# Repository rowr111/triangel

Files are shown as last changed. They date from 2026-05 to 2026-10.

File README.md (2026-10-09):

# triangel

A ceiling light fixture in the shape of a ~50cm equilateral triangle, designed to sit in the corner of a room. Built from 25 triangle PCBs (600 WS2812B LEDs total, 24 per board) and driven by custom firmware that runs ambient and sound-reactive lighting patterns.

The installation runs two pattern setlists - ambient and sound-reactive - with a d-pad, 3-position mode switch, and IR remote for control.

## System overview

Two Baochip-1x chips run under [Xous OS](https://betrusted.io/xous-book/):

- **eye** - drives the 600 WS2812 LEDs as two chains in parallel, one BIO co-processor core each, at 30 fps; manages pattern setlists and handles all user input
- **ear** - captures audio from an ICS43434 MEMS mic, measures it in 24 frequency bands, and streams the result to the eye over UART at about 28 fps. The eye uses the band levels to drive sound-reactive patterns.

## Repository structure

| Directory | Contents |
|---|---|
| [`firmware/`](firmware/README.md) | Rust firmware for both chips and the code they share |
| [`firmware/eye/`](firmware/eye/README.md) | Eye chip firmware - LED output, patterns, input handling |
| [`firmware/ear/`](firmware/ear/README.md) | Ear chip firmware - audio capture, filterbank, UART output |
| [`firmware/shared/`](firmware/shared/README.md) | Shared crate - the ear-to-eye frame format and the sound-reactive tuning |
| [`triangel previewer/`](triangel%20previewer/README.md) | Browser-based LED simulator and desktop audio tools |
| `hardware/` | KiCad PCB design files |
| [`graphics/`](graphics/README.md) | Artwork, assembly sticker sheets, and the scripts that generate them |

## Building the kernels (UART2 freed)

The ear-to-eye link uses UART2 on both chips, but a stock Xous kernel gives UART2 to its
log console. Building with the `gdb-stub` feature leaves it free. CI kernels don't have
it, so both chips use a locally built kernel in manual kernel mode.

From a xous-core checkout:

1. `cargo xtask dabao --feature gdb-stub`
2. Copy `loader.uf2` and `xous.uf2` from `target/riscv32imac-unknown-xous-elf/release/`
   into `firmware/xous_build/`. Both chips flash from that one folder.

The eye also needs a fix to the I2C driver (`libs/bao1x-hal/src/udma/i2c.rs`) that is not
in upstream xous-core, so build from a checkout that has that fix.

## Regenerating the I2S mic driver for different pins

The mic's I2S driver runs as a small precompiled BIO program
(`firmware/ear/src/i2s_bio.rs`, generated from `bio-sim/sw/i2s/main.c`). The mic
pins are compiled into it, so changing the mic wiring means regenerating it - a
firmware constant won't do it. Current pins (these match the schematic and
`firmware/ear/src/pins.rs`): BCLK=PB1, SD=PB2, WS=PB3.

To regenerate:

1. One-time: `pip install ziglang`
2. In `bio-sim/sw/i2s/main.c`, set the pin defines (the number is the PBx pin):

       #define WS_PIN  3
       #define SCK_PIN 1
       #define SD_PIN  2

3. From `bio-sim/sw`, run: `python3 -m ziglang build -Dmodule=i2s -Demit-listing=false`
   (regenerates `bio-sim/sw/i2s/i2s.rs`).
4. Copy it in: `cp bio-sim/sw/i2s/i2s.rs firmware/ear/src/i2s_bio.rs`
5. Rebuild the ear firmware.

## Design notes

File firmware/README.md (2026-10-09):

# triangel - controller firmware

The triangel fixture is driven by two Baochip-1x chips running [Xous OS](https://betrusted.io/xous-book/) (DABAO dev boards used during development):

| Chip | Role |
|---|---|
| **eye** | Drives 600 WS2812 LEDs, handles controls, renders patterns |
| **ear** | Captures audio, runs a 24-band filterbank, streams the result to eye over UART |

See [`eye/`](eye/) and [`ear/`](ear/) for crate-level documentation.

## Physical fixture

The fixture mounts in the corner of a room - an equilateral triangle cutting off the corner tip. It is made of 25 triangle PCBs (24 LEDs each) arranged in a larger triangle:

```
->  1   2   3   4   5   6   7   8   9
<- 16  15  14  13  12  11  10
->     17  18  19  20  21
<-         24  23  22
                25
```

Boards are numbered left-to-right, top-to-bottom by position. The data path snakes for shortest inter-board wire lengths (~52 mm per jump) and is split into two chains, driven in parallel:

| Chain | Eye pin | Enters at | Boards, in order | LEDs |
|---|---|---|---|---|
| 1 | PB4 | board 1 | 1-9, 16, 15, 14 | 288 |
| 2 | PB5 | board 13 | 13, 12, 11, 10, 17-21, 24, 23, 22, 25 | 312 |

## Eye <-> ear communication

The ear sends one frame for each 32 ms of audio it captures, about 28 per second, to the eye over a single UART wire. The frame carries 24 band levels, the overall loudness (absolute and relative to recent music), how sharply the spectrum just rose, and the bass level. The eye turns those into beats, drops, per-band onsets and the Auto sound-mode decision.

The baud rate and frame layout are defined once, in the [`shared/`](shared/) crate that both chips build against; see its README for the byte layout.

## Building

Rust stays at 1.90.0: the Xous library that `install-toolkit` downloads only works with the version it was built for. One-time setup:

```powershell
rustup toolchain install 1.90.0
rustup override set 1.90.0   # in the xous-core checkout and in this repo's root
cargo xtask install-toolkit  # in the xous-core checkout
```

Install the pre-commit hook, which runs the checks in `.pre-commit-config.yaml` before each commit (needs Python):

```powershell
pip install pre-commit
pre-commit install   # in this repo's root
```

Build and flash with the Baochip VS Code extension: out-of-tree, kernel mode manual, kernel files from `firmware/xous_build`. Never use ci-sync; it replaces the kernels built in the root README's "Building the kernels".

## Regenerating the LED map

If the PCB geometry or board gap changes:

```powershell
# 1. In "triangel previewer/": regenerate led_map.js
node generate_map.js

# 2. Copy the output into firmware/eye/src/led/map.rs

# 3. In firmware/eye/: regenerate src/led/geom.rs from map.rs
python tools/gen_geom.py
```

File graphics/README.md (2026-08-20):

# graphics

Artwork and the assembly sticker sheets. Every sheet is 89 x 127 mm - Japanese L size - at
600 dpi.

| File | What |
|---|---|
| `triangel graphic.*` | artwork for triangle shapes |
| `triangel_stickers_L.*` | Tile orientation stickers, 12 mm, 25 numbered + 5 blanks |
| `triangel_input_overlay_L.*` | Input plate overlay, 81 x 61 mm, 1 per sheet |
| `triangel_remote_overlay_L.*` | IR remote overlay, 31 x 51 mm, 4 per sheet |

## Printing

Convenience store photo print on L sticker paper, not document print. PNG and JPG are the
same image - use the JPG if the machine will not take PNG.

## Regenerating

    pwsh graphics\make_input_overlay.ps1
    pwsh graphics\make_remote_overlay.ps1

Windows PowerShell only - they draw with `System.Drawing` - and they write the PNG and JPG
next to themselves. `make_input_overlay.ps1` parses
`../hardware/input-enclosure/InputEnclosure.py`, so the overlay tracks the enclosure.

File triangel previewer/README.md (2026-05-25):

# Triangel Previewer

Browser-based simulator for the Triangel LED installation - 600 LEDs across 25 triangle PCBs. Open `index.html` directly in a browser, no server needed.

## Requirements

- **Node.js** - required only for `bridge.js` (live Baochip data) and `generate_map.js` (regenerating the LED map).
- **npm packages** - install once before using the bridge: `npm install`

## Files

| File | Purpose |
|---|---|
| `index.html` | Renderer - open this in a browser |
| `led_map.js` | Pre-generated LED positions - do not edit by hand |
| `generate_map.js` | Regenerates `led_map.js` - run if geometry changes |
| `bridge.js` | Serial-to-WebSocket bridge for live Baochip data |
| `bridge.config.json` | Bridge configuration |
| `ear_sim.py` | Desktop audio simulator - streams mic or system audio to the ear board over USB serial |

## Live data from the Baochip

When the Baochip is connected, `bridge.js` reads its serial output and streams frames to the browser over a local WebSocket. The browser automatically switches from `animation.js` to live data when the bridge connects, and falls back when it disconnects. A **"bridge live"** indicator appears in the top-right corner.

### Setup

Install dependencies (one time):

```powershell
npm install
```

Edit `bridge.config.json` to set your serial port:

```json
{
  "serial": "COM3",
  "baud": 921600,
  "wsPort": 8080
}
```

Then run the bridge:

```powershell
node bridge.js
```

All config values can be overridden on the command line:

```powershell
node bridge.js --serial COM5 --baud 460800 --ws-port 9000
```

### Frame format

The Baochip sends **1800 bytes per frame** - one RGB triplet per LED, in chain order. Byte offset for a given LED is `chainIdx * 3`. The bridge forwards each complete frame as a binary WebSocket message.

## Chain wiring

Single daisy chain, 600 LEDs in series. Traversal order:

- **Row by row, top to bottom**
- **Right to left within each row**
- **D1->D24 within each board**

Board order in chain (chain positions 0-599):

| Chain pos | Board IDs (right -> left) |
|---|---|
| 0-215 | Row 1: boards 9, 8, 7, 6, 5, 4, 3, 2, 1 |
| 216-383 | Row 2: boards 16, 15, 14, 13, 12, 11, 10 |
| 384-503 | Row 3: boards 21, 20, 19, 18, 17 |
| 504-575 | Row 4: boards 24, 23, 22 |
| 576-599 | Row 5: board 25 |

`chainIdx` in `led_map.js` encodes this for every LED. When the Baochip streams a frame over USB, byte triplet `chainIdx * 3` is the RGB for that LED.

## Desktop audio simulator (ear_sim.py)

`ear_sim.py` streams desktop audio or microphone input to the ear board over USB serial, using the same 1025-byte frame format the real ICS43434 mic produces. This lets the full mel filterbank and UART output path run on real music without the mic circuit being assembled. Build the ear firmware with the `uart-audio` feature to use it.

### Dependencies

```powershell
pip install pyaudiowpatch numpy pyserial
```

### Usage

```powershell
# Stream system speakers (default) to the ear board on COM6
python ear_sim.py

# Use microphone instead
python ear_sim.py --mic

# List available audio devices to find the right index
python ear_sim.py --list-devices

# Specific device index (--mic mode only)
python ear_sim.py --mic --device 2

# Different serial port
python ear_sim.py --port COM4
```

The script auto-detects the WASAPI loopback device for the default speakers. A live bar display shows RMS level and frame rate while running. Press Ctrl+C to stop.

## Regenerating the LED map

Only needed if board geometry or gap size changes:

```powershell
node generate_map.js
```

Tweak `BOARD_GAP` in `generate_map.js` (currently 2mm) to adjust spacing between boards.

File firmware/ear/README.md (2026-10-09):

# triangel - ear firmware

Audio processor firmware for the triangel fixture. Runs on a Baochip-1x under [Xous OS](https://betrusted.io/xous-book/) (DABAO dev board used during development). See [`../README.md`](../README.md) for the overall system and physical fixture description.

## What this is

The **ear** chip captures audio, measures it in 24 frequency bands, and streams the result to the **eye** chip over UART at about 28 fps.

Pipeline per frame (32 ms):

```
mic (I2S, 48 kHz)  ->  2:1 decimate  ->  768-sample frame  ->  24 bandpass filters  ->  normalize  ->  UART TX  ->  eye
```

The 24 bands span 40 Hz to 12 kHz, each a constant ratio above the last (about a third of an octave), so every band covers the same musical interval. It is built like a hardware spectrum analyzer: one bandpass filter per band, squaring and averaging each filter's output over the frame. No FFT is involved, so there is no windowing and the filters run continuously across frame boundaries.

Each frame carries two kinds of value, on purpose:

- **Bands** are normalized against recent music, so they give spectral shape but never go dark in a quiet room.
- **Level** and **bass** are absolute dBFS, so they do. dB SPL is roughly dBFS + 120.

It also carries the level normalized against recent loudness, and the spectral flux the eye uses for beat detection. The frame layout is in [`../shared/README.md`](../shared/README.md).

## Hardware

| Thing | Detail |
|---|---|
| Chip | Baochip-1x - 350 MHz VexRiscv RV32-IMAC, 2 MB SRAM, 4 MB ReRAM, no FPU |
| Microphone | ICS43434 MEMS mic (JLCPCB C5656610), I2S slave, clocked by a BIO core: PB1 = BCLK, PB2 = SD, PB3 = WS |
| Eye link | PB14 (UART2 TX, pin 15) -> eye PB13 (UART2 RX, pin 16), single wire + GND |

## Audio configuration

| Setting | Value | Notes |
|---|---|---|
| Mic sample rate | 48 kHz | Inside the ICS43434's high-performance range |
| Pipeline sample rate | 24 kHz | 2:1 box-average decimation; 12 kHz Nyquist |
| Bit depth | 24-bit | Top 16 bits used |
| Channels | Mono | Select pin tied low on PCB = left channel |
| Frame size | 768 samples | 32 ms of audio per frame. About 28 fps, because audio that arrives while a frame is being processed is skipped |

All of these derive from three constants at the top of [`src/audio.rs`](src/audio.rs).

## Project structure

```
src/
+-- main.rs       - entry point; capture -> filterbank -> UART loop
+-- audio.rs      - I2sAudio: ICS43434 mic through a BIO core
+-- i2s_bio.rs    - the BIO program that clocks the mic (generated)
+-- bands.rs      - BandProcessor: the 24-band filterbank and normalization
+-- uart_out.rs   - UartOut: sends each frame to the eye
+-- pins.rs       - pin assignments
+-- diag.rs       - USB-serial output: boot stages, heartbeat, command input
+-- console.rs    - mic diagnostic commands
```

Code shared with the eye (frame format, tuning) lives in [`../shared/`](../shared/).

## Building

Build via the Baochip VSCode extension (`buildMode: out-of-tree`).

## Mic diagnostic console

The ear has no log console - UART2 carries the audio link to the eye, so the board runs the `gdb-stub` kernel and the log server has no UART left to print on. Everything the firmware reports goes over **USB CDC serial** instead.

The board presents two serial ports: the bootloader's and the running application's. The console is on the application's.

Until the first keystroke the board prints a liveness line every 2 s naming the startup stage it reached and how many bytes it has received, so a stalled boot says where it stopped. Commands are a single character and act on the keystroke - no Enter, because terminals disagree on whether that sends CR, LF, or both.

| Key | What it does |
|---|---|
| `c` | Record 3 s silently, then print the level per 100 ms. The test that answers whether the mic hears you |
| `f` | Measure a quiet second against a noisy one, per octave band. About 30 dB more sensitive than `c`, and works with any sound |
| `r` | Hex-dump the raw 24-bit words after settling |
| `s` | Count samples for 1 s and compare against the expected 48000 Hz |
| `t` | 1 s of statistics: min, max, DC offset, RMS |
| `m` | Live level meter for 15 s |
| `p` | Filterbank time per frame |
| `n` | Live normalization references and the level they scale |
| `?` | Help |

`p`, `n` and `?` are answered without interrupting audio. The rest run on the audio thread between frames, so the eye stops receiving frames while one is in progress - up to 15 s for `m`, 3 s or less for the others. The eye decays to silence after 200 ms without a frame and recovers on its own; because its Auto-mode arm and release times are both 30 s, even the longest command will not flip it out of sound-reactive mode.

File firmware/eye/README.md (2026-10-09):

# triangel - eye firmware

LED controller firmware for the triangel fixture. Runs on a Baochip-1x under [Xous OS](https://betrusted.io/xous-book/) (DABAO dev board used during development). See [`../README.md`](../README.md) for the overall system and physical fixture description.

## What this is

The **eye** chip drives 600 WS2812 LEDs across 25 triangle PCBs. It manages:

- A 30 fps render loop driving two LED chains in parallel, one BIO co-processor core each
- Two pattern setlists (ambient and sound-reactive), stepping every 3 minutes with a transition between patterns
- D-pad + 3-position switch for brightness, pattern stepping, hold, and sound mode
- IR remote (same functions as the physical controls)
- Audio frames from the **ear** chip over UART, from which it detects beats, drops and per-band onsets

## Hardware

| Thing | Detail |
|---|---|
| Chip | Baochip-1x - 350 MHz VexRiscv RV32-IMAC, 2 MB SRAM, 4 MB ReRAM, no FPU |
| BIO cores | 4x PicoRV - two for WS2812 bit-timing, one for IR capture |
| LED output | Two WS2812B chains: PB4 (288 LEDs) and PB5 (312 LEDs) |
| Ear link | PB13 (UART2 RX) |
| Controls | D-pad (5 buttons) + 3-position switch + IR receiver (PC8) |

All pin assignments are in [`src/pins.rs`](src/pins.rs).

## Project structure

```
src/
+-- main.rs      - entry point; 30 fps render loop
+-- setlist.rs   - the two setlists, cycling, transitions, brightness, sound mode
+-- audio.rs     - receives ear frames; beat, drop and activity detection
+-- pins.rs      - pin assignments
+-- diag.rs      - boot stages and heartbeat over USB serial
+-- led/
|   +-- mod.rs          - LedOutput: the WS2812 chains, or the USB previewer
|   +-- ws2812_pair.rs  - two-chain WS2812 driver
|   +-- map.rs          - LED_MAP: world position of every LED (generated)
|   +-- geom.rs         - per-LED distances, angles and grid buckets (generated)
|   +-- grid.rs         - spatial lookup: the LEDs near a point or segment
+-- patterns/
|   +-- mod.rs          - Pattern trait and shared helpers
|   +-- transition.rs   - blends from one pattern to the next
|   +-- glints.rs       - brief white flashes on single LEDs, shared by Shimmer and Rainbow
|   +-- ripples.rs      - raindrop ring trains on black, shared by Raindrop and Drizzle
|   +-- ambient/        - patterns that ignore sound
|   +-- reactive/       - patterns driven by sound
+-- input/
    +-- mod.rs          - InputEvent queue
    +-- buttons.rs      - d-pad and switch polling, debounce
    +-- buttons/        - gpio.rs (wired direct) or expander.rs (input board over I2C)
    +-- ir.rs, nec_capture.rs, nec_rx.rs - IR remote, NEC decoded on a BIO core
    +-- previewer.rs    - on-screen controls from the previewer
```

Code shared with the ear (frame format, sound tuning) lives in [`../shared/`](../shared/).

## Building

Build via the Baochip VSCode extension (`buildMode: out-of-tree`). Optional features can be added under **Extra Features** in the extension settings:

| Feature | Purpose |
|---|---|
| `previewer` | Send LED frames over USB serial to the browser simulator instead of driving WS2812, and take on-screen control input |
| `bringup` | Stream boot stages, a heartbeat, audio link stats and IR activity over USB serial. Silent when combined with `previewer`, whose serial stream is binary |
| `input-board` | Read the d-pad and switch from the separate input board (MCP23008 over I2C) instead of eye GPIOs |

## Using the previewer

The previewer is a browser-based LED simulator at `../../triangel previewer/`. It can receive live frames from this firmware over USB serial.

1. Enable the `previewer` feature in the Baochip extension settings and build
2. Flash and boot the DABAO
3. In the previewer directory: `npm install` (first time), then `node bridge.js`
4. Open `index.html` in a browser - it will show the live pattern output

Bridge defaults: COM3, 921600 baud, WebSocket port 8080. Override via `bridge.config.json` or CLI flags.

## Adding a pattern

See [PATTERNS.md](PATTERNS.md).

## Sound reactivity

Each render frame, reactive patterns get an `Audio` snapshot built from the ear's frames: 24 band levels, a per-band onset (`rise`), overall loudness relative to recent music, and one-frame `beat` and `drop` flags. Detection thresholds and every pattern's sound tuning are in [`../shared/src/tuning.rs`](../shared/src/tuning.rs).

Sound mode is set by the 3-position switch, or cycled by the remote's gear button:

| Position | Behaviour |
|---|---|
| Off | Always the ambient setlist |
| Auto | The reactive setlist once the room has been loud for a sustained stretch, back to ambient once it has been quiet for one |
| On | Always the reactive setlist |

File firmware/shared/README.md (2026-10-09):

# triangel-shared

Code both chips build against, so the **ear** (audio) and the **eye** (LEDs) cannot disagree. No dependencies and no OS requirements.

## `frame` - the ear -> eye frame

The ear sends one `BandFrame` for each 32 ms of audio it captures, about 28 per second, over UART. Baud rate, band count and frame length are constants in [`src/frame.rs`](src/frame.rs) (`EAR_UART_BAUD`, `BAND_COUNT`, `FRAME_LEN`).

### Wire format (58 bytes, little-endian)

| Offset | Size | Content |
|---|---|---|
| 0x00 | 1 | Sync byte `0xAA` |
| 0x01-0x30 | 48 | `bands`: 24 x u16, band 0 (lowest) first |
| 0x31-0x32 | 2 | `level`: overall loudness, absolute dBFS |
| 0x33-0x34 | 2 | `level_norm`: loudness relative to the recent loudest and quietest |
| 0x35-0x36 | 2 | `flux`: how much the whole spectrum rose this frame |
| 0x37-0x38 | 2 | `bass`: level of the lowest bands, absolute dBFS |
| 0x39 | 1 | XOR checksum of bytes 0x01-0x38 |

`bands` are normalized against recent music, so they show spectral shape but never go dark in a quiet room. `level` and `bass` are absolute, so they do. dB SPL is roughly dBFS + 120 with this microphone.

Values go on and off the wire through `level_to_wire` / `level_from_wire` (dBFS) and `norm_to_wire` / `norm_from_wire` (0.0-1.0).

### Usage

```rust
use triangel_shared::frame::{BandFrame, FRAME_LEN};

// ear
let mut buf = [0u8; FRAME_LEN];
frame.encode(&mut buf);

// eye - None on a bad sync byte or checksum
if let Some(frame) = BandFrame::decode(&buf) { /* ... */ }
```

The eye receives a byte stream, not whole frames. `FrameAssembler::feed` takes one byte at a time, finds the sync byte, and returns a `BandFrame` each time one completes.

## `tuning` - sound-reactive tuning

Every knob for beat, onset and drop detection, the Auto sound-mode switch, each reactive pattern, and the ear's normalization, in one file: [`src/tuning.rs`](src/tuning.rs). The `ear` section needs the ear reflashed and `BASS_BANDS` needs both chips; everything else only the eye.

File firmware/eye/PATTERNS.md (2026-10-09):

# Writing patterns

A pattern implements the `Pattern` trait in `src/patterns/mod.rs`: called once per frame with the current time and this frame's `Audio`, it fills in a color per LED. Ambient patterns live in `src/patterns/ambient/` and ignore `audio`; sound-reactive ones live in `src/patterns/reactive/`.

## Minimal example

```rust
// src/patterns/ambient/your_pattern.rs
use crate::audio::Audio;
use crate::led::map::LED_MAP;
use crate::patterns::{Frame, Pattern};

pub struct YourPattern;

impl Pattern for YourPattern {
    fn render(&mut self, t_ms: u32, _audio: &Audio, out: &mut Frame) {
        for (i, led) in LED_MAP.iter().enumerate() {
            // led.wx, led.wy - position in mm
            out[i] = [r, g, b];
        }
    }
}
```

Then:

1. Add `pub mod your_pattern;` to `src/patterns/ambient/mod.rs` (or `reactive/mod.rs`).
2. Add `Box::new(YourPattern)` to `ambient_patterns()` (or `reactive_patterns()`) in `src/setlist.rs`.

`out[i]` belongs to `LED_MAP[i]`. `t_ms` is a `u32` and wraps after 49.7 days, so compare times with `wrapping_sub`, never `<` or `>=`.

A pattern is only rendered while it is on screen or fading out, so time jumps when it comes back. Override `on_enter(&mut self, t_ms)` to reset whatever should start fresh each time it comes on screen; it runs before the first frame after the pattern has been off screen for more than half a second.

## World coordinates

```
origin: top-left of fixture
x: increases rightward, 0-517 mm
y: increases downward,  0-436 mm

WORLD_CX  = 258 mm  - horizontal centre
WORLD_TOP =   6 mm  - topmost LED
WORLD_BOT = 436 mm  - apex (board 25, room corner)
WORLD_H   = 430 mm  - total height
```

These constants, plus `WORLD_CENTROID_X` / `WORLD_CENTROID_Y`, are in `crate::led::map`.

## Utilities

```rust
// src/patterns/mod.rs
hsv(h, s, v) -> [u8; 3]     // h: 0-360, s/v: 0-1
lerp(a, b, t) -> f32
sin_sum(a_sin, a_cos, b_sin, b_cos)  // sin(a + b); see Performance
mix_rgb(a, b, t)            // lerp per channel, f32 RGB
ramp(&stops, t)             // color along (position, color) stops
smoothstep(t) -> f32        // clamped to 0-1
wrap360(h) -> f32           // hue into 0-360, for inputs within one turn of range
cycle(t_ms, period_ms)      // 0-1 position in a repeating period
fold_ms(t_ms, rate)         // t_ms folded to one period of a rad/ms rate
hash2(a, b), knuth_hash(x), tile_hash(led)
Rng::new(seed)              // .f32(), .next_u32(), .range_u32(min, max), .below(n), .pick(&items)
free_or_oldest(slots, now_ms, is_free, start_ms)  // a free slot in a pool, else the oldest
Shot                        // a flash held then faded; .level(t_ms), .end_ms()
phase_phasors()             // see Performance
```

Shared building blocks:

- `glints::Glints` / `GlintStyle` - brief white flashes on single LEDs, landing mostly on the bright ones. Draw the frame, then call `update` over it.
- `ripples::Ripples` / `RippleStyle` - raindrop ring trains on black. The pattern picks where and when a drop lands (`spot`, `land`); `draw` renders.

Fixed geometry in `crate::led::geom` (generated by `tools/gen_geom.py`): per LED, `DIST_C[i]` and `THETA_C[i]` (distance and angle from the centroid) and `DIST_APEX[i]`; per board, by board id, `BOARD_CENTER` and `BOARD_Y_RANGE`; and `BOARD_COUNT`, `LEDS_PER_BOARD`, `DIST_C_MAX`. The triangle's left and right edges are `WORLD_LEFT` / `WORLD_RIGHT` in `crate::led::world`.

`crate::led::grid` buckets LEDs by position: `for_each_near(x, y, reach, f)` and `for_each_near_seg(a, b, reach, f)` call `f` with the index of each LED near a point or a segment.

## Performance

The chip has no floating-point hardware, so every `f32` operation is a library call and `sin`/`atan2`/`sqrt`/`powf` cost hundreds of cycles. A frame is 33 ms, of which about 9.4 ms goes to clocking out the strips - one `sin` per LED is affordable, six is not. Keep work out of the per-LED loop:

- Values fixed by LED position belong in `led::geom` or a table built in `new()`, not recomputed each frame.
- Localized shapes scatter over `led::grid` rather than every LED testing every source.
- `sin(per_led + per_frame)` needs no `sin` per LED: store `sin`/`cos` of the per-LED part, take `sin`/`cos` of the frame's angle once, and combine them with `sin_sum`. `phase_phasors()` covers hash-quantized offsets.
- Integer math per LED where possible, as Shimmer and Flame do: values in Q12 (x4096 = 1.0), lookup tables for curves and colors. A few float calls per frame are fine.
- Wrap time to the term's period before converting to `f32` (`(t_ms % PERIOD_MS) as f32`): raw `t_ms` loses sub-frame precision after hours of uptime.

The previewer caps at 30 fps and runs a few ms faster than the fixture, so it can show a pattern is too slow but can't confirm one is fast enough.

## Sound-reactive patterns

`Audio` (`src/audio.rs`) is this frame's view of the sound:

| Field | Meaning |
|---|---|
| `bands: [f32; 24]` | Band levels 0-1, lowest frequency first. Normalized, so they keep their shape when quiet |
| `rise: [f32; 24]` | How far each band just jumped above its own recent average, 0-1 |
| `level_norm` | Loudness relative to recent music, 0-1 |
| `beat`, `beat_strength` | `beat` is true for the one frame a beat lands; strength is 0-1 |
| `drop` | True for the one frame the bass returns after a breakdown |

A reactive pattern has to look good at every level, silence included.

Put a reactive pattern's tuning constants in their own module in `../shared/src/tuning.rs`, alongside the detection thresholds they interact with.

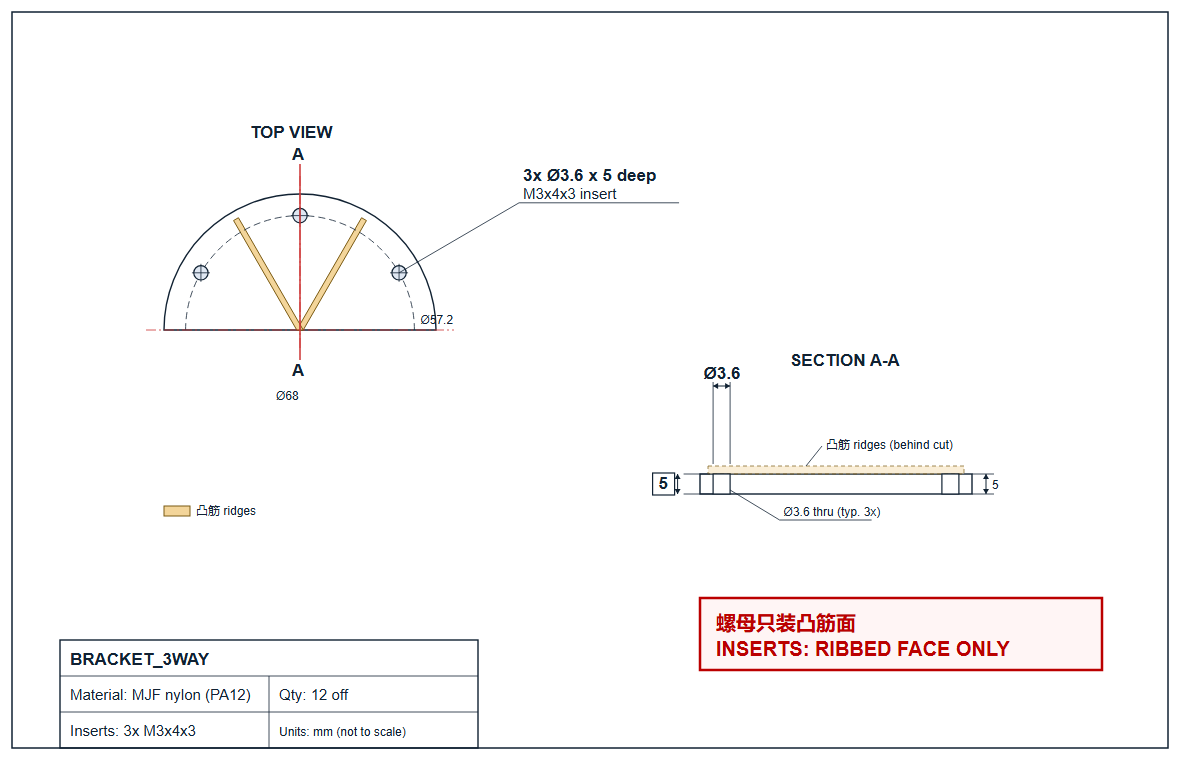
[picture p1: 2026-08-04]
hardware/brackets/triangel brackets/BRACKET_3WAY_insert_drawing.png

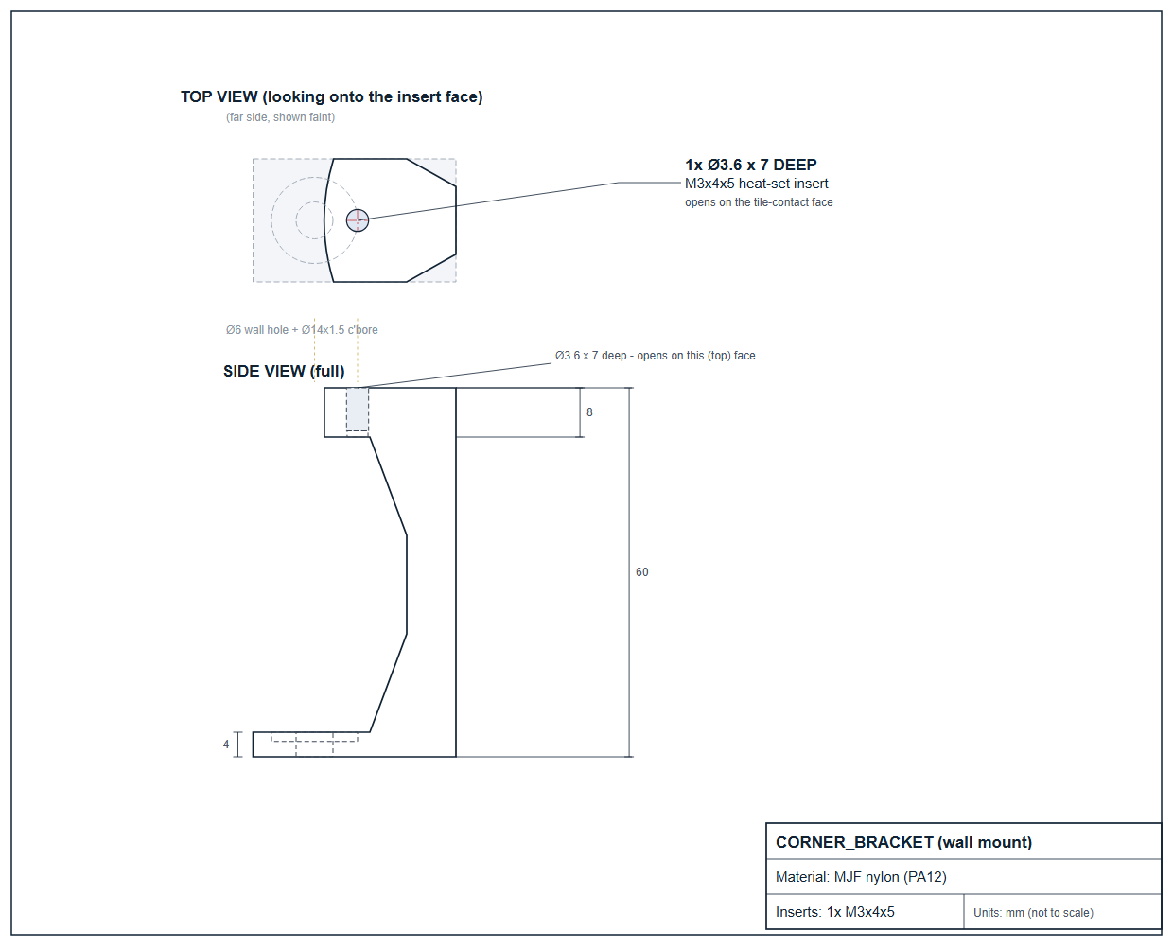
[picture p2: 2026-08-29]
hardware/brackets/CornerBrackets/CORNER_BRACKET_insert_drawing.png

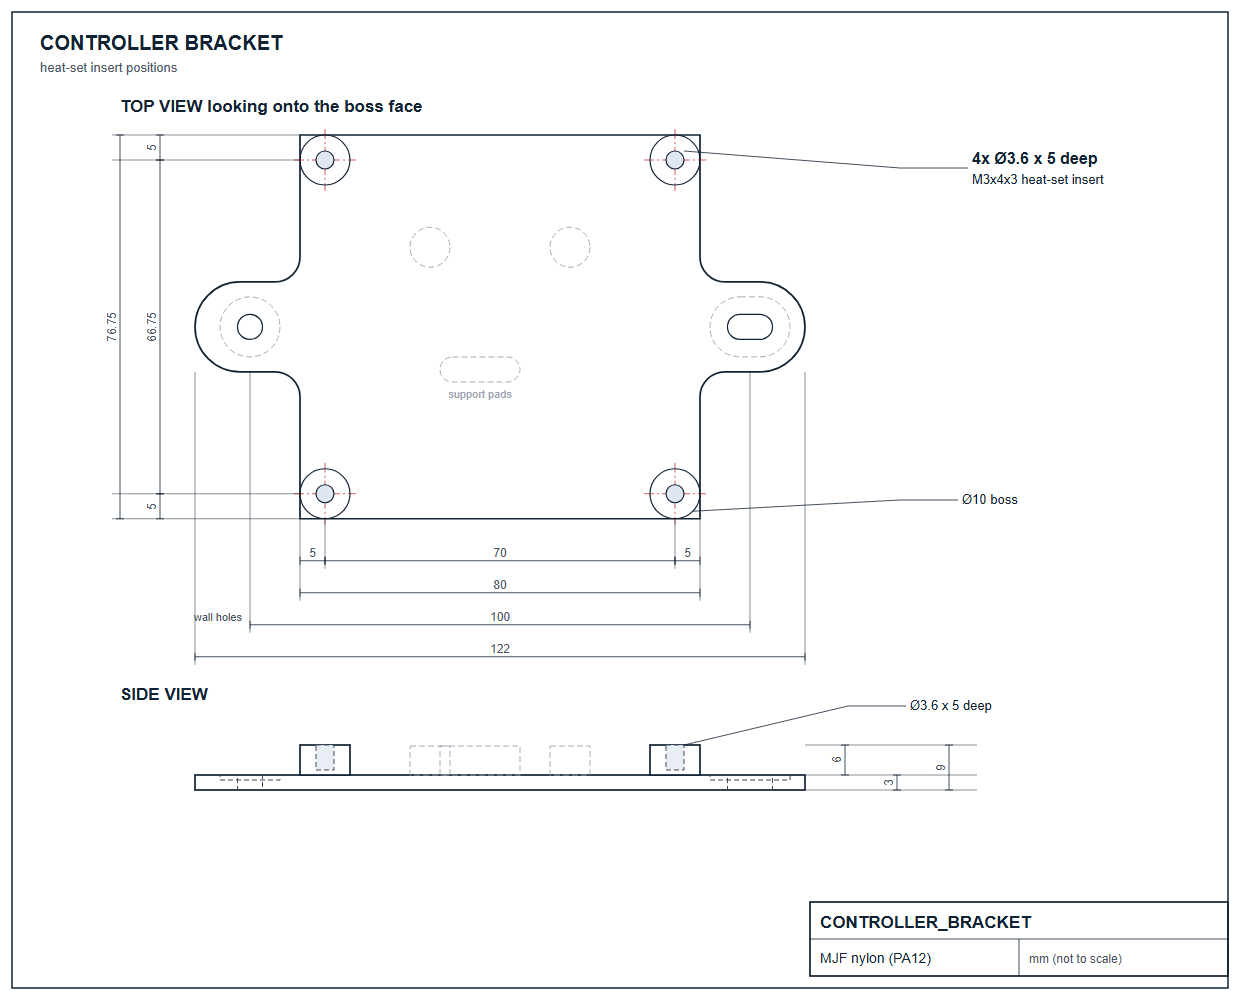
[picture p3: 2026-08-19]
hardware/brackets/controller bracket/CONTROLLER_BRACKET_insert_drawing.png

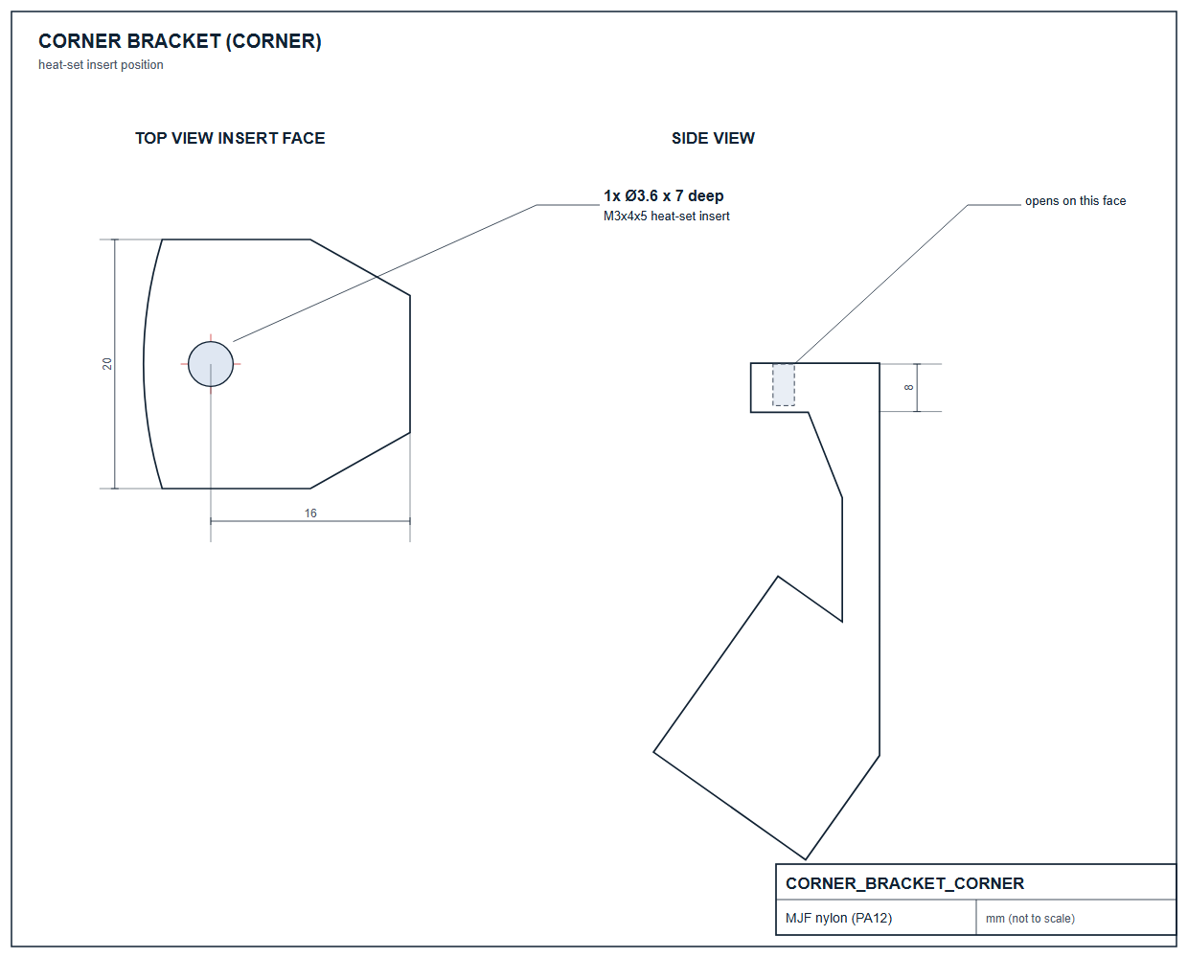
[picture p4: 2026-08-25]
hardware/brackets/CornerBracketsCorner/CORNER_BRACKET_CORNER_insert_drawing.png

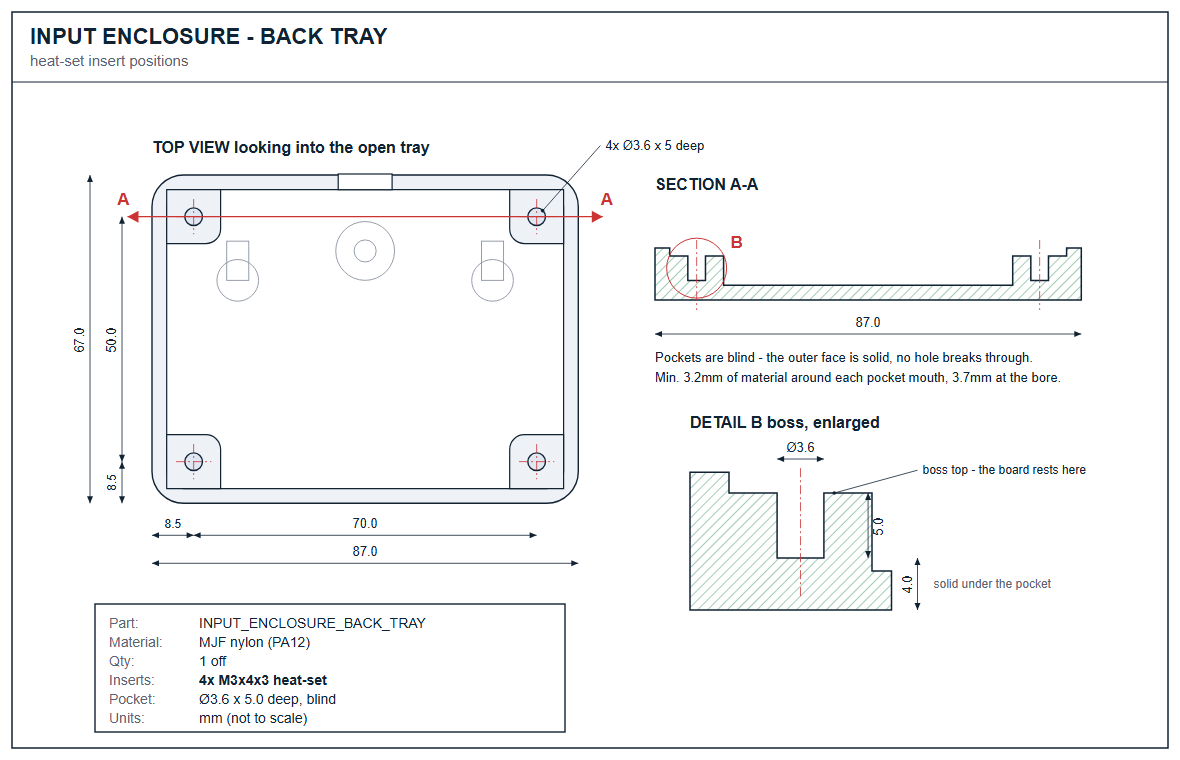
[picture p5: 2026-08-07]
hardware/input-enclosure/BACKTRAY_insert_drawing.png

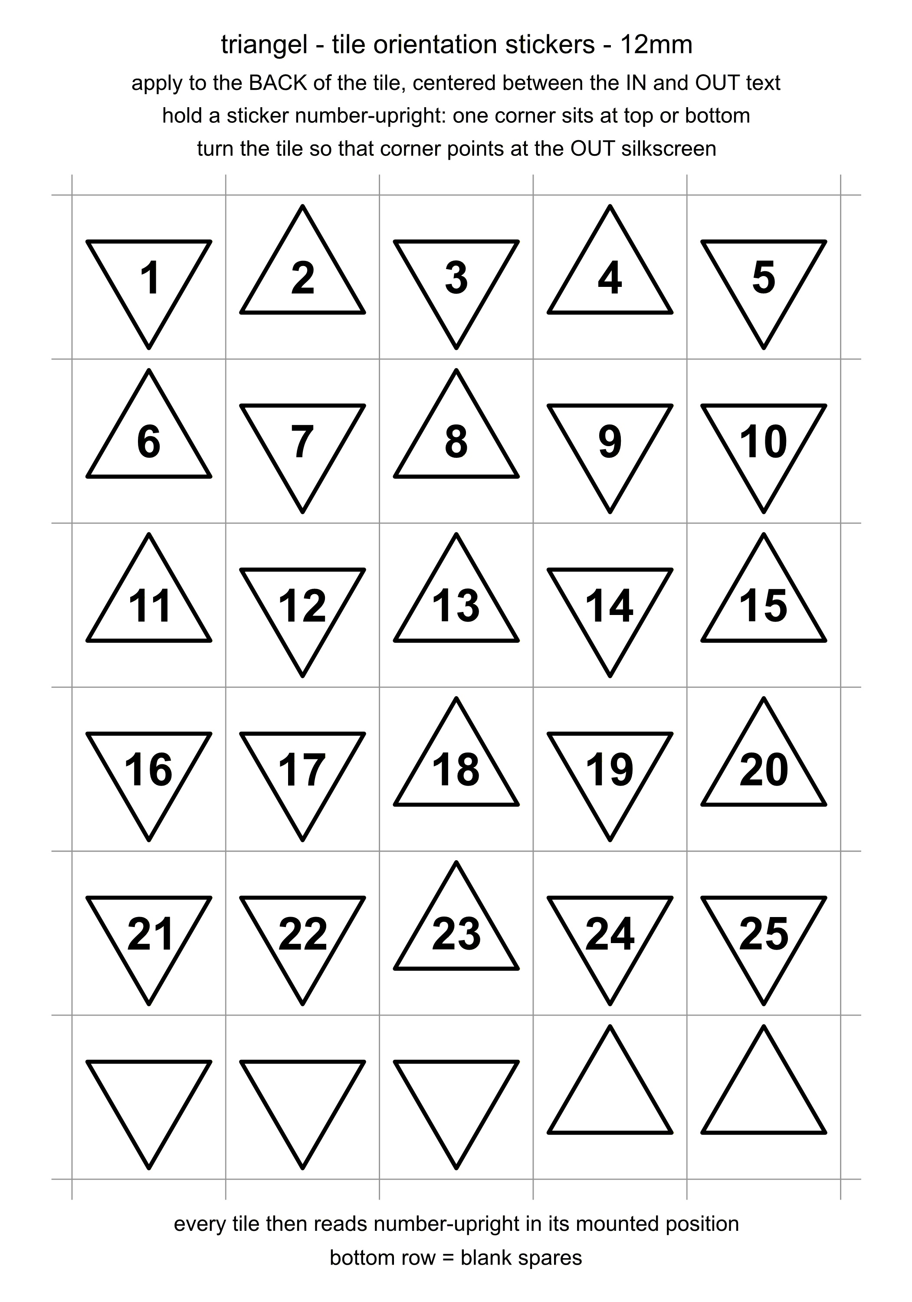
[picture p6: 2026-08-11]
graphics/triangel_stickers_L.jpg

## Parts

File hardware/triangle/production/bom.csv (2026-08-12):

Designator | Footprint | Quantity | Value | LCSC Part #
C1, C10, C11, C12, C13, C14, C15, C16, C17, C18, C19, C2, C20, C21, C22, C23, C24, C3, C4, C5, C6, C7, C8, C9 | 0402 | 24 | 100nF | C1525
C26 | 0402 | 1 | 33nF | C507072
C27, C28, C30, C31, C33, C34 | 0603 | 6 | 10µF | C96446
D1, D10, D11, D12, D13, D14, D15, D16, D17, D18, D19, D2, D20, D21, D22, D23, D24, D3, D4, D5, D6, D7, D8, D9 | LED_WS2812B-2020_PLCC4_2.0x2.0mm - no silkscreen | 24 | WS2812B-2020 | C52917434
J1, J2 | TYPE-C-SMD_USB4120-03-C | 2 | USB_C_Receptacle_USB2.0_16P | C3151749
L1 | L_Changjiang_FNR4030S | 1 | 4.7uH | C167874
R1, R2 | 0603 | 2 | 33Ω | C23140
R3, R9 | 0402 | 2 | 100kΩ | C60491
R4 | 0402 | 1 | 560kΩ | C132339
U2 | SOT-23-6_L2.9-W1.6-P0.95-LS2.8-BR | 1 | EA8212HT6R | C609568

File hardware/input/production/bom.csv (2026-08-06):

Designator | Footprint | Quantity | Value | LCSC Part #
C1, C4 | 0402 | 2 | 100nF | C1525
C2, C3 | 0603 | 2 | 4.7µF | C19666
CGQ1 | SENSOR-SMD_IRM-H638T-TR2-TL | 1 | IRM-H638T/TR2 | C91447
R1 | 0603 | 1 | 100Ω | C22775
SW1, SW2, SW3, SW4, SW5 | SW-SMD_PANASONIC_EVPASXXX | 5 | EVP-ASAC1A | C4365033
SW6 | SW-SMD_CL-SB-13A-0X | 1 | CL-SB-13A-02T | C2921655
U1 | SSOP-20_L7.2-W5.3-P0.65-LS7.8-TL | 1 | MCP23008T-E/SS | C629435
USBC1 | USB-C_SMD-TYPE-C-31-M-12_1 | 1 | TYPE-C-31-M-12 | C165948

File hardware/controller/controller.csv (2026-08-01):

Reference | Qty | Value | DNP | Exclude from BOM | Footprint | Datasheet | LCSC Part #
C1 | 1 | 1µF |  |  | Capacitor_SMD:C_0603_1608Metric | https://jlcpcb.com/api/file/downloadByFileSystemAccessId/8556213788459761664 | C15849
C2,C3,C5,C6,C8,C9 | 6 | 100nF |  |  | Capacitor_SMD:C_0402_1005Metric | https://www.lcsc.com/datasheet/lcsc_datasheet_2304140030_Samsung-Electro-Mechanics-CL05B104KO5NNNC_C1525.pdf | C1525
C14,C16,C23,C24,C33,C34,C35 | 7 | 10µF |  |  | Capacitor_SMD:C_0603_1608Metric | https://jlcpcb.com/api/file/downloadByFileSystemAccessId/8568525238768373760 | C96446
C27 | 1 | 33nF |  |  | Capacitor_SMD:C_0402_1005Metric | https://www.lcsc.com/datasheet/lcsc_datasheet_2304140030_Samsung-Electro-Mechanics-CL05B104KO5NNNC_C1525.pdf | C507072
C30 | 1 | 4.7µF |  |  | Capacitor_SMD:C_0603_1608Metric | https://jlcpcb.com/api/file/downloadByFileSystemAccessId/8579707103462166528 | C19666
J1,J2 | 2 | TYPE-C 16PLT-H10.0 |  |  | easyeda2kicad:TYPE-C-SMD_USB4120-03-C | https://www.usb.org/sites/default/files/documents/usb_type-c.zip | C3151749
MK1 | 1 | ICS-43434 |  |  | Sensor_Audio:InvenSense_ICS-43434-6_3.5x2.65mm | https://www.invensense.com/wp-content/uploads/2016/02/DS-000069-ICS-43434-v1.2.pdf | C5656610
R1,R4,R5,R6,R7,R8,R9,R10 | 8 | 10kΩ |  |  | Resistor_SMD:R_0603_1608Metric | https://jlcpcb.com/api/file/downloadByFileSystemAccessId/8579706381320323072 | C25804
R2 | 1 | 100kΩ |  |  | Resistor_SMD:R_0603_1608Metric | https://jlcpcb.com/api/file/downloadByFileSystemAccessId/8579706350726930432 | C25803
R3 | 1 | 100Ω |  |  | Resistor_SMD:R_0603_1608Metric | https://jlcpcb.com/api/file/downloadByFileSystemAccessId/8579706114222985216 | C22775
R16,R20 | 2 | 100kΩ |  |  | Resistor_SMD:R_0402_1005Metric | https://jlc-prod-smt.oss-eu-central-1.aliyuncs.com/smtDataManualFile/8738158350643609600-C60491.pdf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 | C60491
R18 | 1 | 560kΩ |  |  | Resistor_SMD:R_0402_1005Metric | https://jlc-prod-smt.oss-eu-central-1.aliyuncs.com/smtDataManualFile/8586178827076296704-C132339.pdf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 | C132339
U5,U6 | 2 | SN74LVC1T45DBV |  |  | Package_TO_SOT_SMD:SOT-23-6 | http://www.ti.com/lit/ds/symlink/sn74lvc1t45.pdf | C7843
SW2 | 1 | CL-SB-13A-02T |  |  | easyeda2kicad:SW-SMD_CL-SB-13A-0X | https://www.lcsc.com/datasheet/C2921655.pdf | C2921655
U8 | 1 | EA8212HT6R |  |  | easyeda2kicad:SOT-23-6_L2.9-W1.6-P0.95-LS2.8-BR | https://lcsc.com/product-detail/DC-DC-Converters_Everanalog-IC-design-EA8212HT6R_C609568.html | C609568
SW1,SW3,SW4,SW5,SW6 | 5 | EVP-ASAC1A |  |  | easyeda2kicad:SW-SMD_PANASONIC_EVPASXXX | https://www.lcsc.com/datasheet/C4365033.pdf | C4365033
L2 | 1 | 4.7uH |  |  | Inductor_SMD:L_Changjiang_FNR4030S | https://lcsc.com/product-detail/Inductors-SMD_microgate-MGFL2012F2R2MT-LF_C281115.html | C167874
CGQ1 | 1 | IRM-H638T/TR2 |  |  | easyeda2kicad:SENSOR-SMD_IRM-H638T-TR2-TL | https://lcsc.com/product-detail/Infrared-Sensors_IRM-H638T-TR2_C91447.html | C91447
U10 | 1 | XDJK-0051-025 |  |  | easyeda2kicad:DC-IN-TH_XDJK-0051-025 | https://www.lcsc.com/datasheet/C7498153.pdf | C7498153
U1,U2,U3,U4 | 4 | ZX-PM2.54-1-16PY |  |  | easyeda2kicad:HDR-TH_16P-P2.54-V-F-1 | https://www.lcsc.com/datasheet/C7499334.pdf | C7499334

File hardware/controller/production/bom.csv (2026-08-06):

Designator | Footprint | Quantity | Value | LCSC Part #
C1 | 0603 | 1 | 1µF | C15849
C14, C16, C23, C24, C33, C34, C35, C36 | 0603 | 8 | 10µF | C96446
C2, C5, C6, C8, C9 | 0402 | 5 | 100nF | C1525
C27 | 0402 | 1 | 33nF | C507072
J1, J2, J3 | TYPE-C-SMD_USB4120-03-C | 3 | TYPE-C 16PLT-H10.0 | C3151749
L2 | L_Changjiang_FNR4030S | 1 | 4.7uH | C167874
MK1 | InvenSense_ICS-43434-6_3.5x2.65mm | 1 | ICS-43434 | C5656610
R1, R3, R4 | 0603 | 3 | 10kΩ | C98220
R16, R20 | 0402 | 2 | 100kΩ | C60491
R18 | 0402 | 1 | 560kΩ | C132339
R2 | 0603 | 1 | 100kΩ | C25803
R6, R8 | 0603 | 2 | 2.2kΩ
U1, U2, U3, U4 | HDR-TH_16P-P2.54-V-F-1 | 4 | ZX-PM2.54-1-16PY | C7499334
U10 | DC-IN-TH_XDJK-0051-025 | 1 | XDJK-0051-025 | C7498153
U5, U6 | SOT-23-6 | 2 | SN74LVC1T45DBV | C7843
U8 | SOT-23-6_L2.9-W1.6-P0.95-LS2.8-BR | 1 | EA8212HT6R | C609568

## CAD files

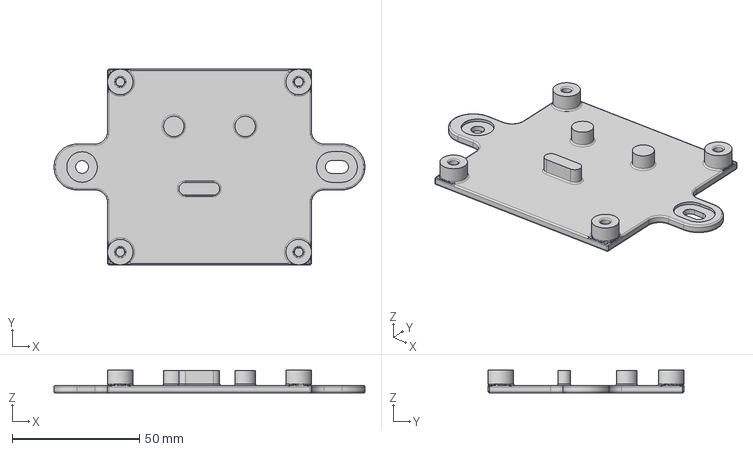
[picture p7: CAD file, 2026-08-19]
hardware/brackets/controller bracket/controller_bracket.step
122.0 x 76.8 x 9.00 mm

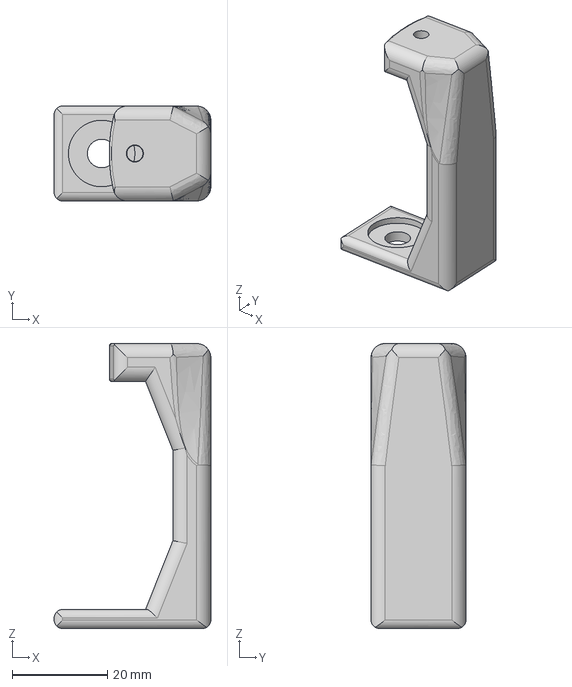
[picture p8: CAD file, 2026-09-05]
hardware/brackets/CornerBrackets/triangle brackets - corner bracket.step
33.0 x 20.0 x 60.0 mm

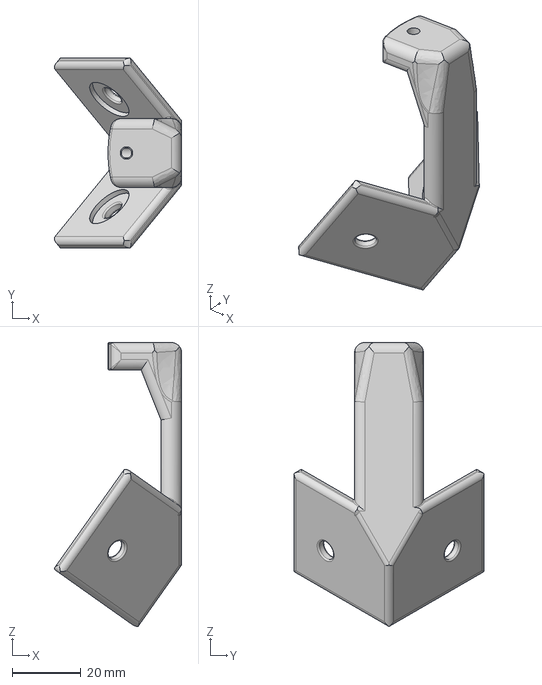
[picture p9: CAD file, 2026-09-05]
hardware/brackets/CornerBracketsCorner/triangle brackets - corner bracket corner.step
36.9 x 55.1 x 82.4 mm

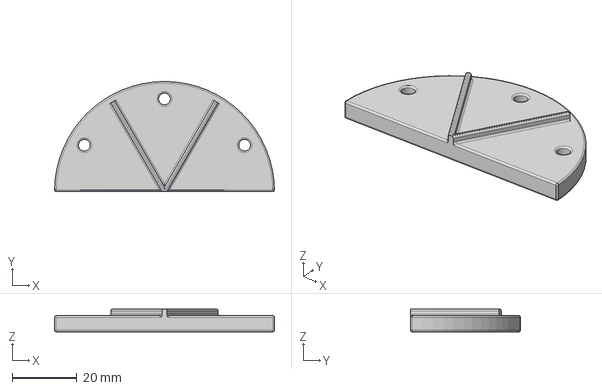
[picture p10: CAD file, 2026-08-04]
hardware/brackets/triangel brackets/triangle bracket - 3 way.step
68.0 x 34.0 x 7.00 mm

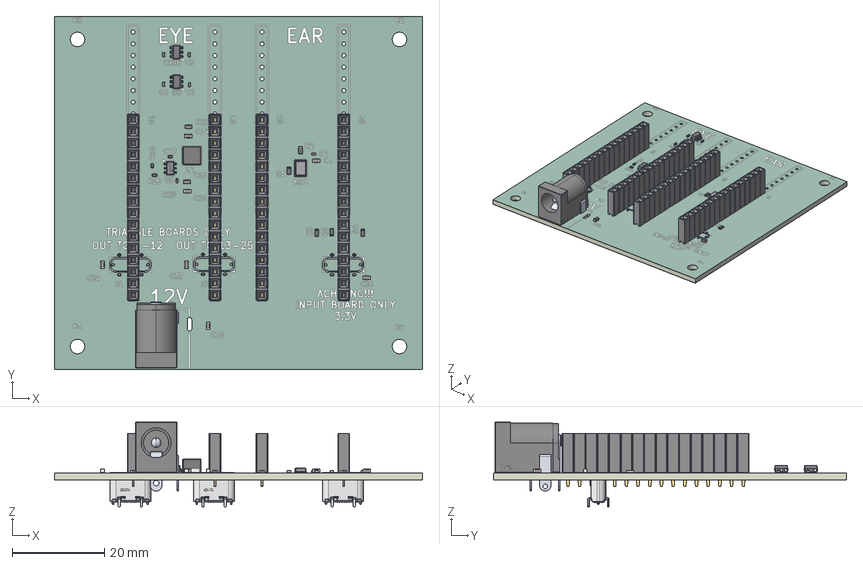
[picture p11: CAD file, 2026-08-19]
hardware/controller/controller.step
80.0 x 76.8 x 18.5 mm
HDR2.54-F-LI-1X16P x 4
C_0603_1608Metric x 9
C_0402_1005Metric x 6
R_0603_1608Metric x 6
SOT-23-6_L2.9-W1.6-H1.5-LS2.8-P0.95
InvenSense_ICS-43434-6_3.5x2.65mm
SOT-23-6 x 2
L_Changjiang_FNR4030S
R_0402_1005Metric x 3
TYPE-C-SMD_USB4120-03-C x 3
DC-IN-TH_XDJK-0051-025
controller_silkscreen
controller_soldermask x 2
controller_PCB

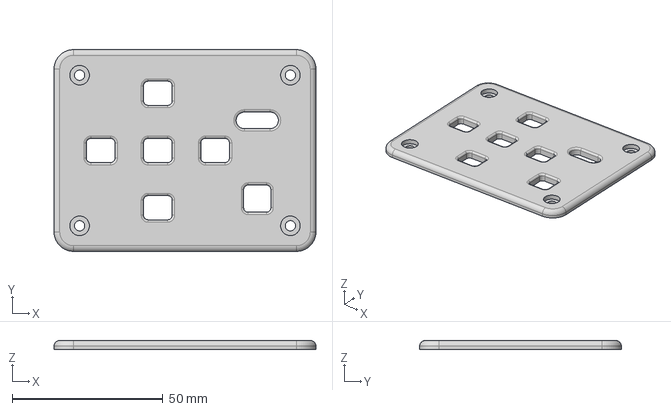
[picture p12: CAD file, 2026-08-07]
hardware/input-enclosure/input-board-front-plate.step
87.0 x 67.0 x 3.00 mm

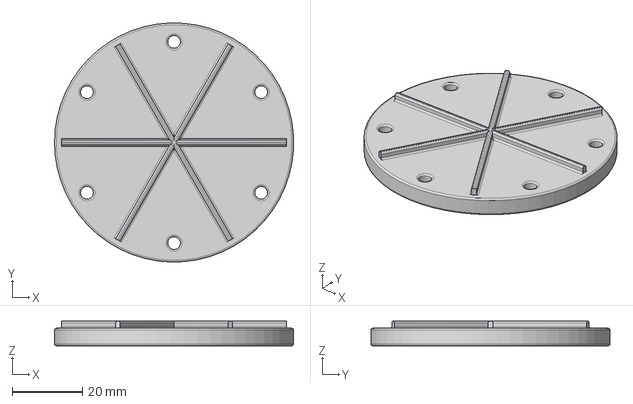
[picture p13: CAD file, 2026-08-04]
hardware/brackets/triangel brackets/triangle bracket - 6 way.step
67.9 x 68.0 x 7.00 mm

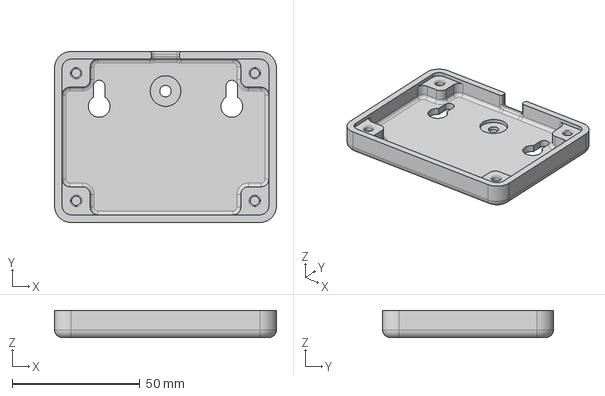
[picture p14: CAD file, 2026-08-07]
hardware/input-enclosure/input-board-back-tray.step
87.0 x 67.0 x 10.6 mm

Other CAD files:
hardware/brackets/triangel brackets/triangle brackets.f3d

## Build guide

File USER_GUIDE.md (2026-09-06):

# Triangel - user guide

## Updating the firmware

Two small boards, called DABAO boards, sit in sockets on the controller board and
each runs its own firmware. The sockets are labeled EYE and EAR. Each board has a
RESET and a PROG button, and its own USB-C connector.

Both boards start their firmware as soon as they get power - there is nothing to
press.

To load new firmware, put a board into its bootloader:

1. Plug a USB-C cable from your computer into the board you want to update.
2. Hold down PROG.
3. Still holding PROG, press RESET and release it.
4. Keep holding PROG for about another second, then release it.

The board appears on your computer as a removable drive. Copy the new `.uf2` files
onto it, then press PROG once more to restart into the new firmware.

RESET on its own will not get you into the bootloader - it just restarts the
firmware. PROG has to be held as the board comes out of reset.

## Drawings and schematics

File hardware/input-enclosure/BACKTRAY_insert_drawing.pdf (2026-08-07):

## INPUT ENCLOSURE - BACK TRAY

A A

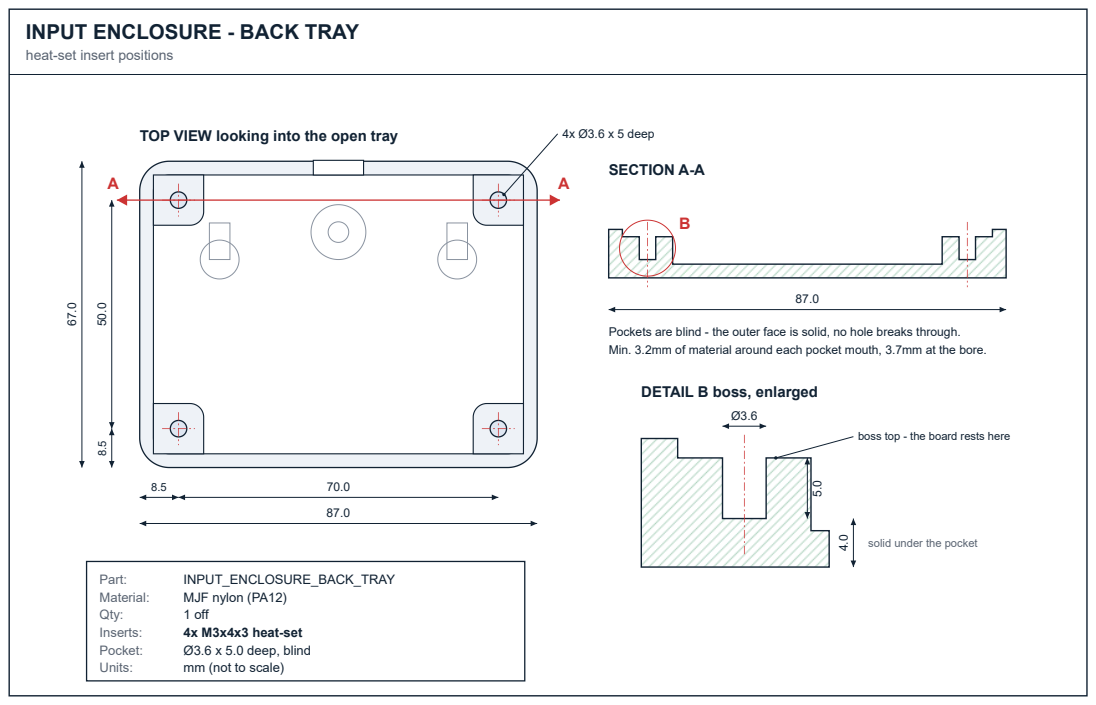
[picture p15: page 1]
4x Ø3.6 x 5 deep; SECTION A-A; Part:; INPUT_ENCLOSURE_BACK_TRAY; Material:; MJF nylon (PA12); Qty:; 1 off; Inserts:; 4x M3x4x3 heat-set; Pocket:; Ø3.6 x 5.0 deep, blind; Units:; mm (not to scale)

heat-set insert positions

TOP VIEW looking into the open tray

Pockets are blind - the outer face is solid, no hole breaks through.
Min. 3.2mm of material around each pocket mouth, 3.7mm at the bore.

DETAIL B boss, enlarged

boss top - the board rests here

solid under the pocket

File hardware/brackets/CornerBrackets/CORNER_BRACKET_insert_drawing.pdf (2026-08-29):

## TOP VIEW (looking onto the insert face)

## 1x Ø3.6 x 7 DEEP

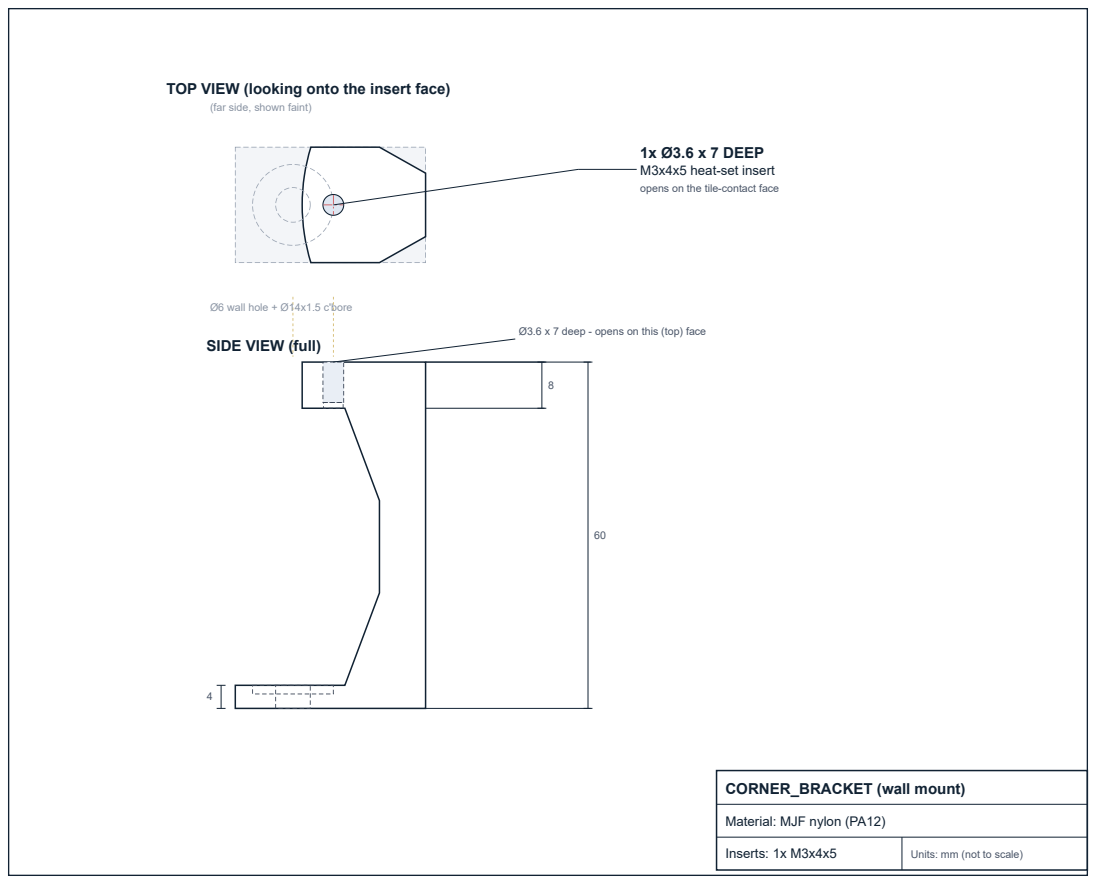
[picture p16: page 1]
CORNER_BRACKET (wall mount); Inserts: 1x M3x4x5; Units: mm (not to scale)

(far side, shown faint)

M3x4x5 heat-set insert
opens on the tile-contact face

Ø6 wall hole + Ø14x1.5 c'bore

Ø3.6 x 7 deep - opens on this (top) face

SIDE VIEW (full)

Material: MJF nylon (PA12)

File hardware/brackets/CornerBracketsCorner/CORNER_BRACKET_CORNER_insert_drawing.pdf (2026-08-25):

## CORNER BRACKET (CORNER)

### TOP VIEW INSERT FACE

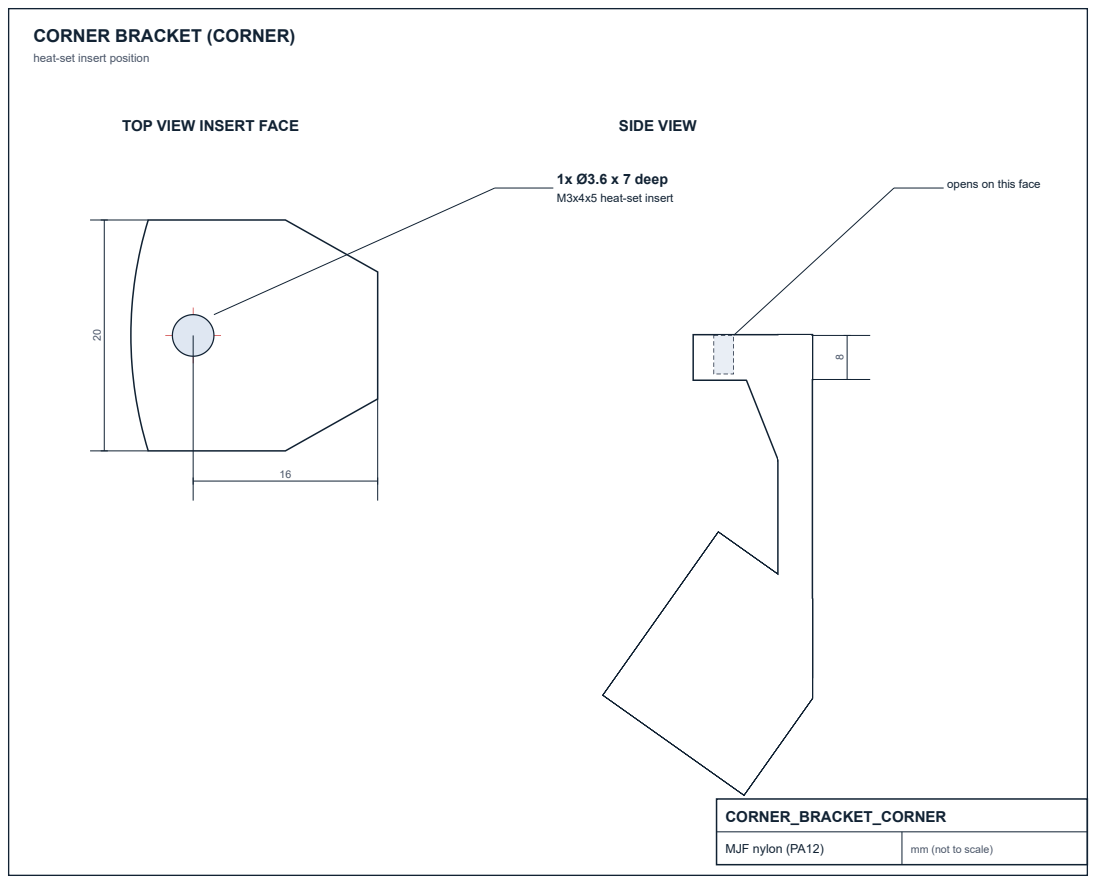
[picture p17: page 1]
SIDE VIEW; CORNER_BRACKET_CORNER; MJF nylon (PA12); mm (not to scale)

heat-set insert position

1x Ø3.6 x 7 deep
M3x4x5 heat-set insert

opens on this face

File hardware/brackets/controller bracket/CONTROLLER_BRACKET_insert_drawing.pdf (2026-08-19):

## CONTROLLER BRACKET

### TOP VIEW looking onto the boss face

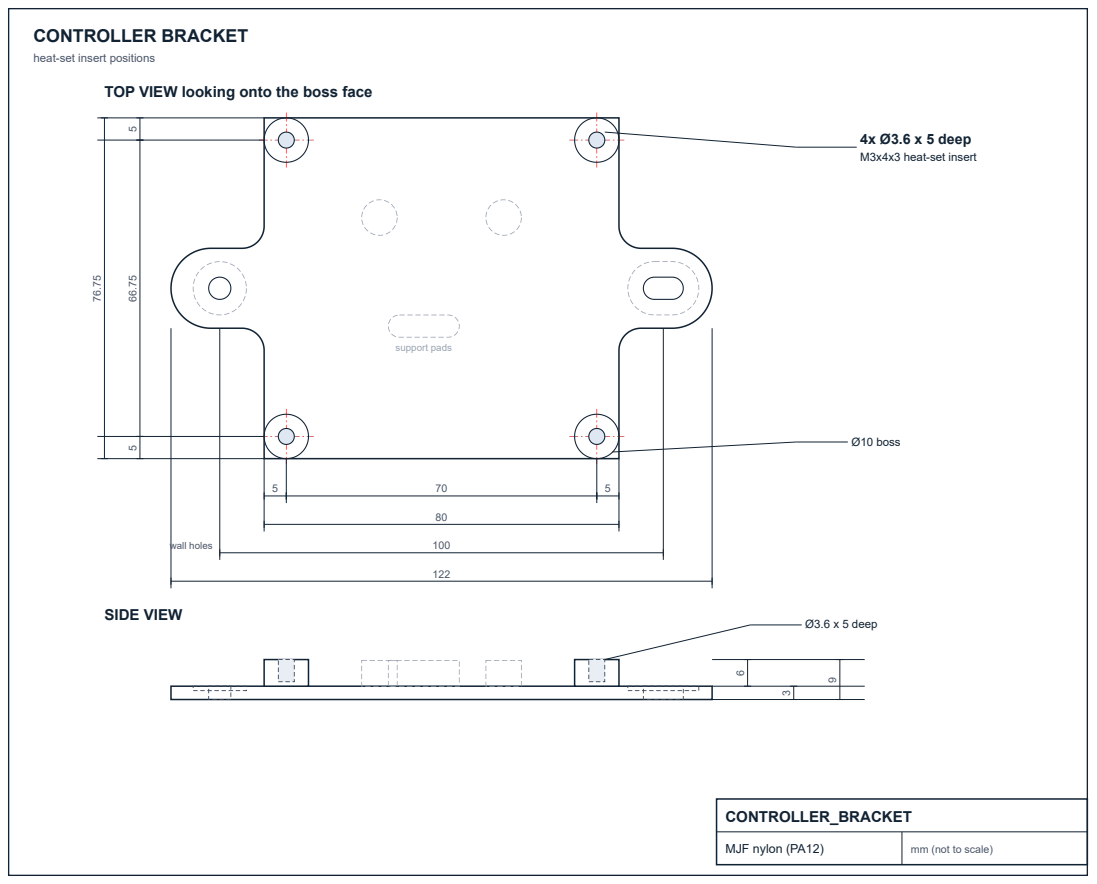
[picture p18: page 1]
support pads; Ø10 boss; wall holes; SIDE VIEW; Ø3.6 x 5 deep; CONTROLLER_BRACKET; MJF nylon (PA12); mm (not to scale)

heat-set insert positions

4x Ø3.6 x 5 deep
M3x4x3 heat-set insert

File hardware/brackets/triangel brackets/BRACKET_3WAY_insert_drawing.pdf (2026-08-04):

A

## TOP VIEW

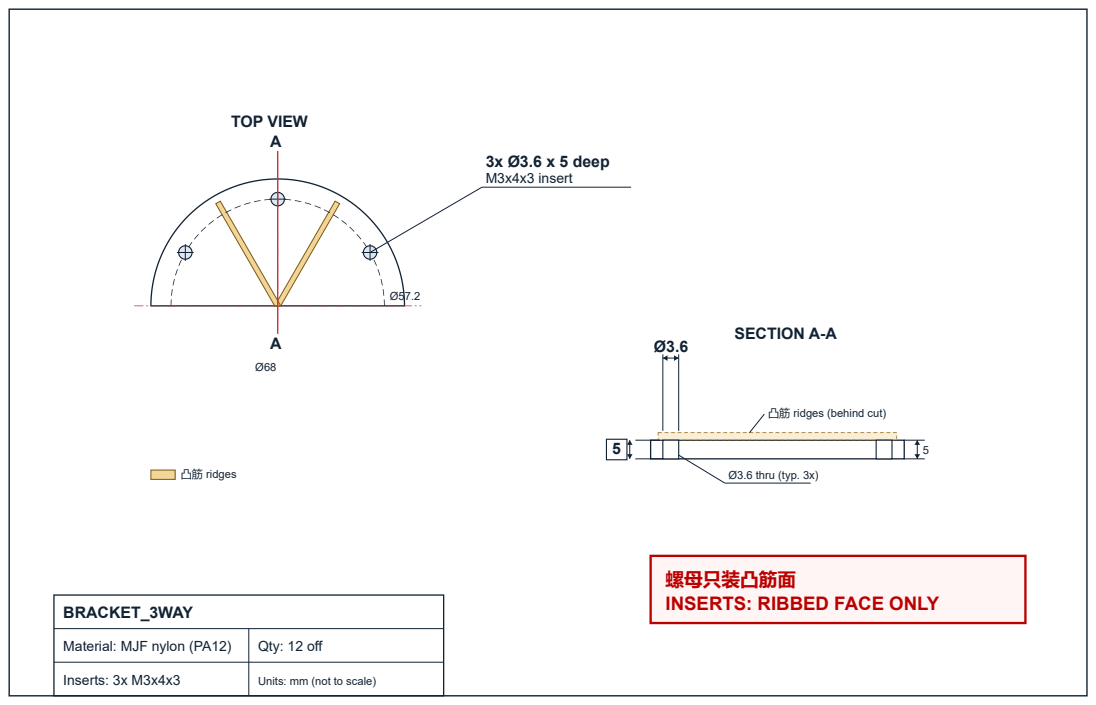
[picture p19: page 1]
3x Ø3.6 x 5 deep M3x4x3 insert; 凸筋 ridges; SECTION A-A; Ø3.6 thru (typ. 3x); 螺母只装凸筋面; Material: MJF nylon (PA12); Qty: 12 off; Inserts: 3x M3x4x3; Units: mm (not to scale)

凸筋 ridges (behind cut)

INSERTS: RIBBED FACE ONLY BRACKET_3WAY

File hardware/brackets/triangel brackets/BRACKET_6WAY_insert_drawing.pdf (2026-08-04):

A

## TOP VIEW

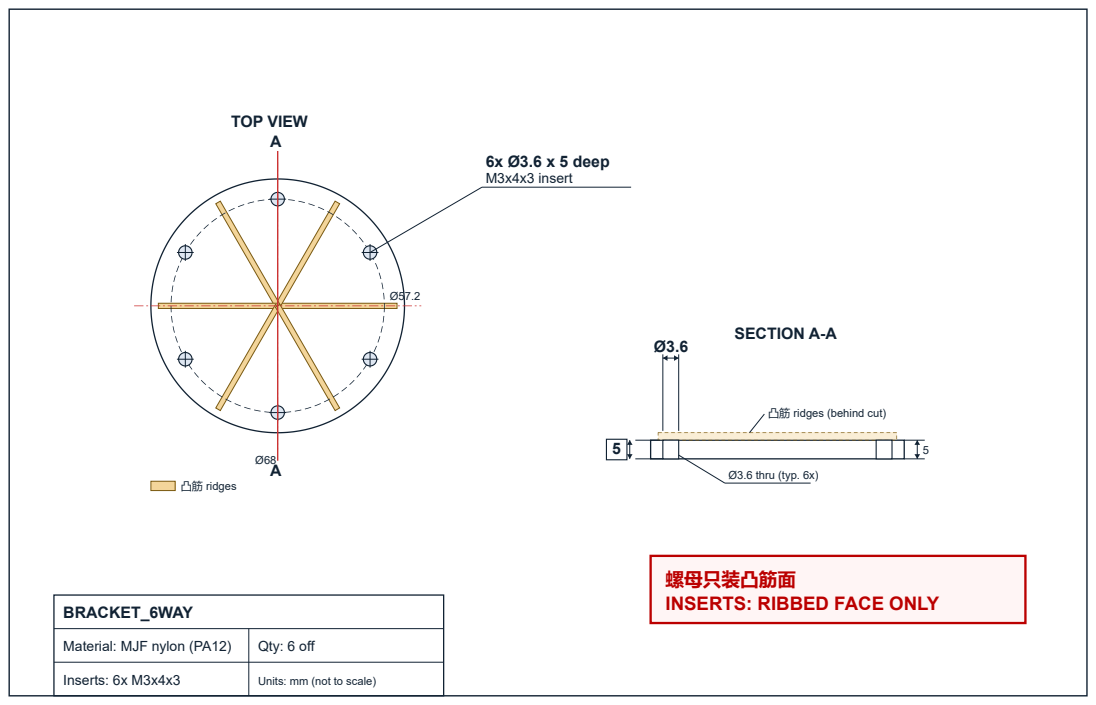
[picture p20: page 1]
6x Ø3.6 x 5 deep M3x4x3 insert; 凸筋 ridges; SECTION A-A; Ø3.6 thru (typ. 6x); 螺母只装凸筋面; Material: MJF nylon (PA12); Qty: 6 off; Inserts: 6x M3x4x3; Units: mm (not to scale)

凸筋 ridges (behind cut)

INSERTS: RIBBED FACE ONLY BRACKET_6WAY

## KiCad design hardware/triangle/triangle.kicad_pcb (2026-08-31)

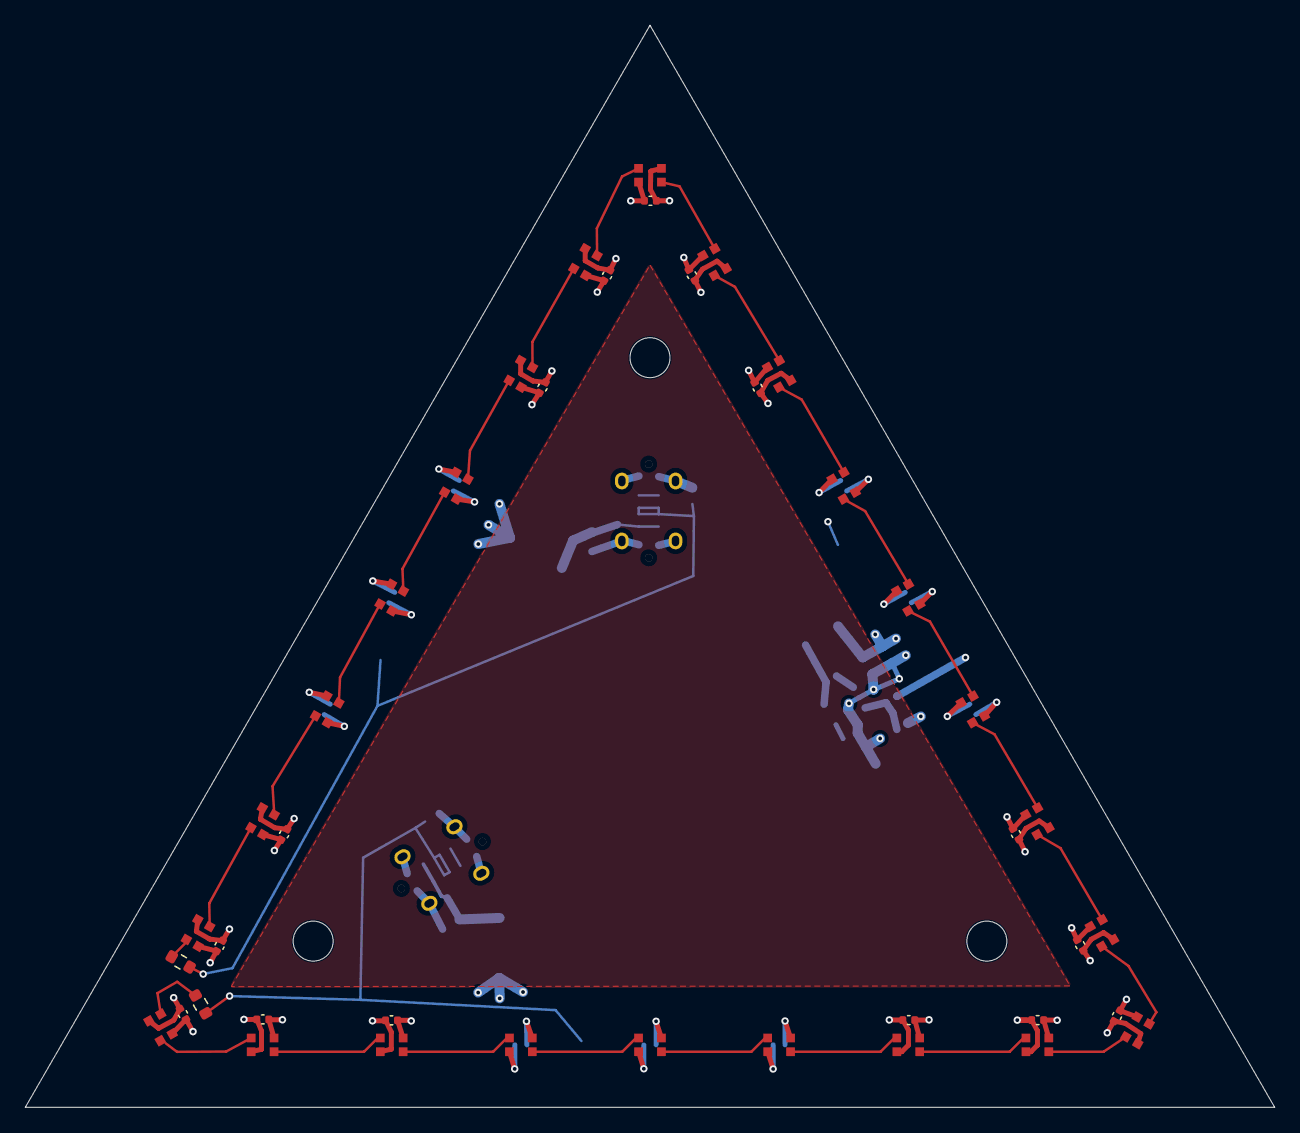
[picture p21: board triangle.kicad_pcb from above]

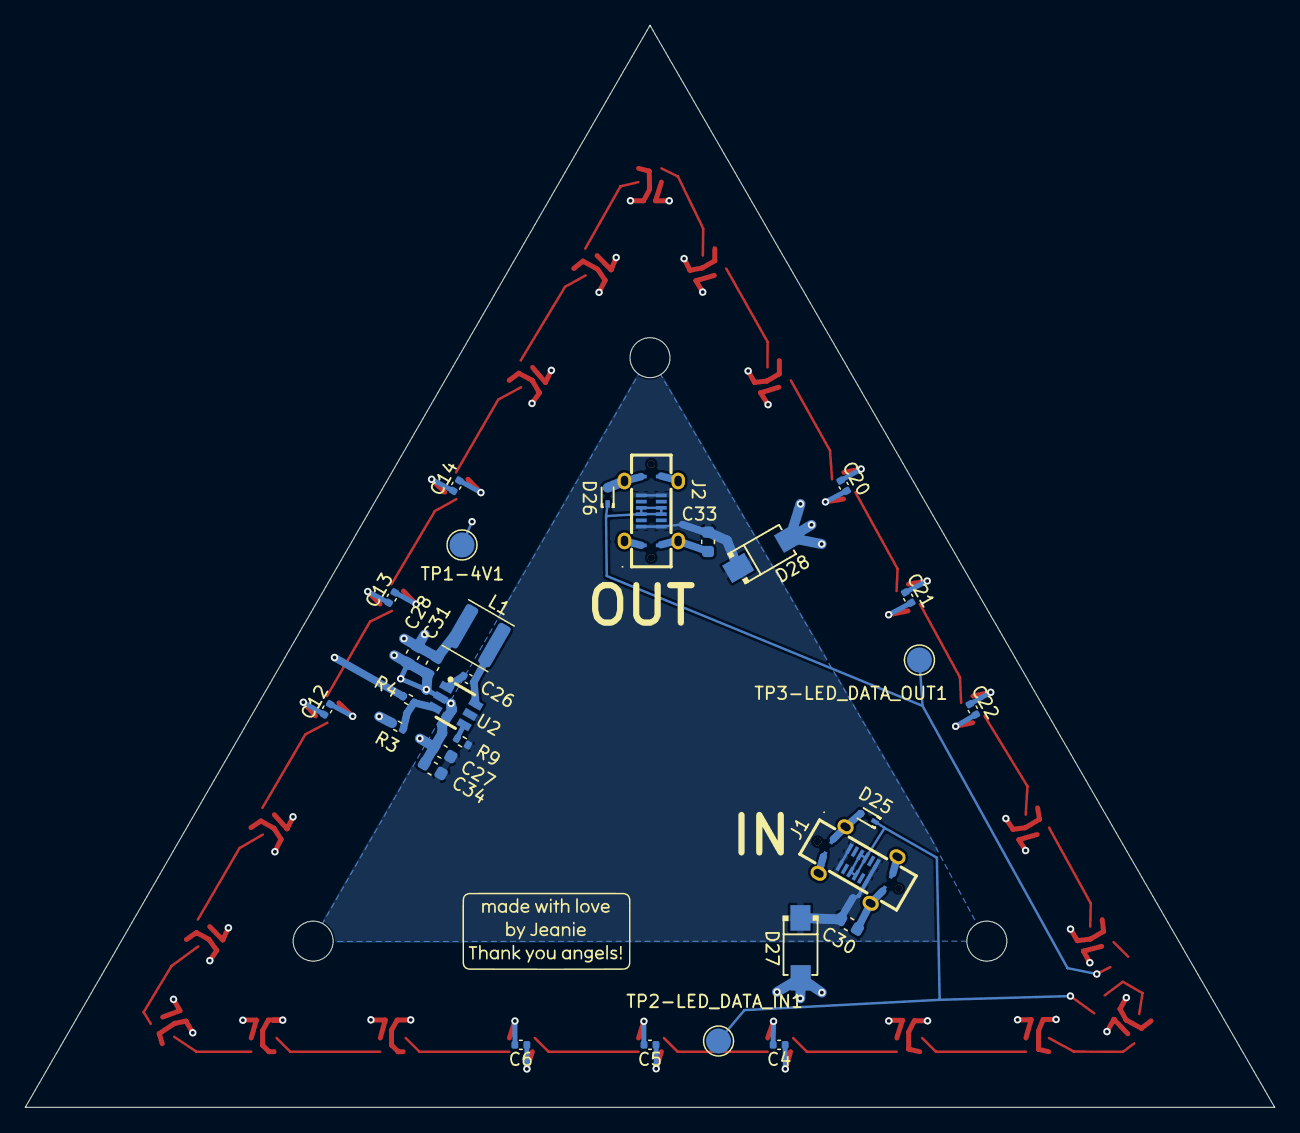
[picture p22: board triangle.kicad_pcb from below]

Board: 4 copper layers, 100.0 x 86.6 mm, 74 parts (30 on the bottom side), 34 nets.

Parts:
C1, C2, C3, C4, C5, C6, C7, C8, C9, C10, C11, C12, C13, C14, C15, C16, C17, C18, C19, C20, C21, C22, C23, C24: 100nF; C_0402_1005Metric
C26: 33nF; C_0402_1005Metric
C27, C28, C30, C31, C33, C34: 10µF; C_0603_1608Metric
D1, D2, D3, D4, D5, D6, D7, D8, D9, D10, D11, D12, D13, D14, D15, D16, D17, D18, D19, D20, D21, D22, D23, D24: WS2812B-2020; LED_WS2812B-2020_PLCC4_2.0x2.0mm - no silkscreen
D25, D26: ESD8351XV2T1G_C19829478; SOD-523_L1.2-W0.8-LS1.6-RD
D27, D28: SMAJ15A_C19077535; SMA_L4.3-W2.6-LS5.0-RD
H1, H2, H3: MountingHole; MountingHole_3.2mm_M3
J1, J2: USB_C_Receptacle_USB2.0_16P; TYPE-C-SMD_USB4120-03-C
L1: 4.7uH; L_Changjiang_FNR4030S
R1, R2: 33Ω; R_0603_1608Metric
R3, R9: 100kΩ; R_0402_1005Metric
R4: 560kΩ; R_0402_1005Metric
TP1-4V1, TP2-LED_DATA_IN1, TP3-LED_DATA_OUT1: TestPoint; TestPoint_Pad_D2.0mm
U2: EA8212HT6R; SOT-23-6_L2.9-W1.6-P0.95-LS2.8-BR

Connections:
+4V: C1.1, C2.1, C3.1, C4.1, C5.1, C6.1, C7.1, C8.1, C9.1, C10.1, C11.1, C12.1, C13.1, C14.1, C15.1, C16.1, C17.1, C18.1, C19.1, C20.1, C21.1, C22.1, C23.1, C24.1, C28.1, C31.1, D1.4 (VDD), D2.4 (VDD), D3.4 (VDD), D4.4 (VDD), D5.4 (VDD), D6.4 (VDD), D7.4 (VDD), D8.4 (VDD), D9.4 (VDD), D10.4 (VDD), D11.4 (VDD), D12.4 (VDD), D13.4 (VDD), D14.4 (VDD), D15.4 (VDD), D16.4 (VDD), D17.4 (VDD), D18.4 (VDD), D19.4 (VDD), D20.4 (VDD), D21.4 (VDD), D22.4 (VDD), D23.4 (VDD), D24.4 (VDD), L1.2, R4.2, TP1-4V1.1 (1_1)
+12V: C27.1, C30.1, C33.1, C34.1, D27.1 (K), D28.1 (K), J1.A4 (VBUS), J1.A9 (VBUS), J1.B4 (VBUS), J1.B9 (VBUS), J2.A4 (VBUS), J2.A9 (VBUS), J2.B4 (VBUS), J2.B9 (VBUS), R9.2, U2.5 (PWR)
GND: C1.2, C2.2, C3.2, C4.2, C5.2, C6.2, C7.2, C8.2, C9.2, C10.2, C11.2, C12.2, C13.2, C14.2, C15.2, C16.2, C17.2, C18.2, C19.2, C20.2, C21.2, C22.2, C23.2, C24.2, C27.2, C28.2, C30.2, C31.2, C33.2, C34.2, D1.2 (VSS), D2.2 (VSS), D3.2 (VSS), D4.2 (VSS), D5.2 (VSS), D6.2 (VSS), D7.2 (VSS), D8.2 (VSS), D9.2 (VSS), D10.2 (VSS), D11.2 (VSS), D12.2 (VSS), D13.2 (VSS), D14.2 (VSS), D15.2 (VSS), D16.2 (VSS), D17.2 (VSS), D18.2 (VSS), D19.2 (VSS), D20.2 (VSS), D21.2 (VSS), D22.2 (VSS), D23.2 (VSS), D24.2 (VSS), D25.2 (A), D26.2 (A), D27.2 (A), D28.2 (A), J1.0 (EH), J1.A1 (GND), J1.A12 (GND), J1.B1 (GND), J1.B12 (GND), J2.0 (EH), J2.A1 (GND), J2.A12 (GND), J2.B1 (GND), J2.B12 (GND), R3.2, U2.2 (GND)
LED_DATA_IN: D25.1 (C), J1.A6 (DP1), J1.A7 (DN1), J1.B6 (DP2), J1.B7 (DN2), R1.1, TP2-LED_DATA_IN1.1 (1_1)
LED_DATA_OUT: D26.1 (C), J2.A6 (DP1), J2.A7 (DN1), J2.B6 (DP2), J2.B7 (DN2), R2.2, TP3-LED_DATA_OUT1.1 (1_1)
unnamed: D1.3 (DIN), R1.2
unnamed: D1.1 (DOUT), D2.3 (DIN)
unnamed: D2.1 (DOUT), D3.3 (DIN)
unnamed: D3.1 (DOUT), D4.3 (DIN)
unnamed: D4.1 (DOUT), D5.3 (DIN)
unnamed: D5.1 (DOUT), D6.3 (DIN)
unnamed: D6.1 (DOUT), D7.3 (DIN)
unnamed: D7.1 (DOUT), D8.3 (DIN)
unnamed: D8.1 (DOUT), D9.3 (DIN)
unnamed: D9.1 (DOUT), D10.3 (DIN)
unnamed: D10.1 (DOUT), D11.3 (DIN)
unnamed: D11.1 (DOUT), D12.3 (DIN)
unnamed: D12.1 (DOUT), D13.3 (DIN)
unnamed: D13.1 (DOUT), D14.3 (DIN)
unnamed: D14.1 (DOUT), D15.3 (DIN)
unnamed: D15.1 (DOUT), D16.3 (DIN)
unnamed: D16.1 (DOUT), D17.3 (DIN)
unnamed: D17.1 (DOUT), D18.3 (DIN)
unnamed: D18.1 (DOUT), D19.3 (DIN)
unnamed: D19.1 (DOUT), D20.3 (DIN)
unnamed: D20.1 (DOUT), D21.3 (DIN)
unnamed: D21.1 (DOUT), D22.3 (DIN)
unnamed: D22.1 (DOUT), D23.3 (DIN)
unnamed: D23.1 (DOUT), D24.3 (DIN)
unnamed: D24.1 (DOUT), R2.1
unnamed: C26.1, U2.1 (BOOT)
unnamed: R3.1, R4.1, U2.3 (FBK)
unnamed: R9.1, U2.4 (RUN)
unnamed: C26.2, L1.1, U2.6 (SWITCH)

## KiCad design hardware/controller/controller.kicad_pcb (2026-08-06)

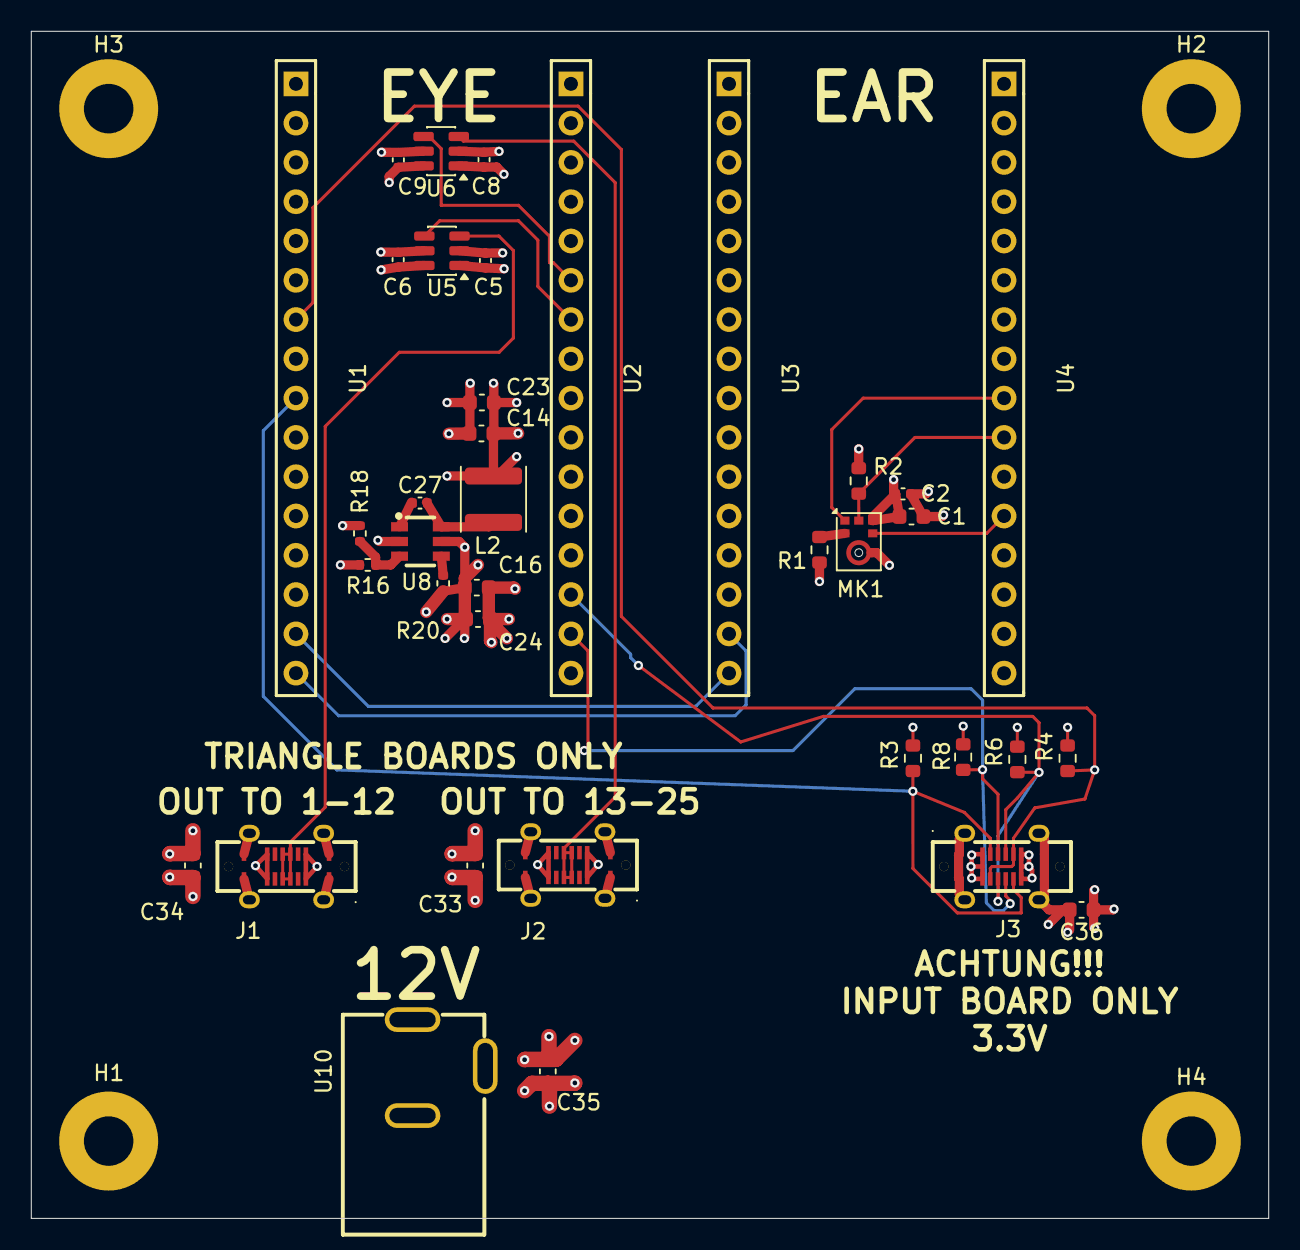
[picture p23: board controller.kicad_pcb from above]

Board: 4 copper layers, 80.0 x 76.8 mm, 41 parts (0 on the bottom side), 22 nets.

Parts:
C1: 1µF; C_0603_1608Metric
C2, C5, C6, C8, C9: 100nF; C_0402_1005Metric
C14, C16, C23, C24, C33, C34, C35, C36: 10µF; C_0603_1608Metric
C27: 33nF; C_0402_1005Metric
H1, H2, H3, H4: MountingHole; MountingHole_3.2mm_M3_Pad
J1, J2, J3: TYPE-C 16PLT-H10.0; TYPE-C-SMD_USB4120-03-C
L2: 4.7uH; L_Changjiang_FNR4030S
MK1: ICS-43434; InvenSense_ICS-43434-6_3.5x2.65mm
R1, R3, R4: 10kΩ; R_0603_1608Metric
R2: 100kΩ; R_0603_1608Metric
R6, R8: 2.2kΩ; R_0603_1608Metric
R16, R20: 100kΩ; R_0402_1005Metric
R18: 560kΩ; R_0402_1005Metric
U1, U2, U3, U4: ZX-PM2.54-1-16PY; HDR-TH_16P-P2.54-V-F-1
U5, U6: SN74LVC1T45DBV; SOT-23-6
U8: EA8212HT6R; SOT-23-6_L2.9-W1.6-P0.95-LS2.8-BR
U10: XDJK-0051-025; DC-IN-TH_XDJK-0051-025

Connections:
+3.3V: C1.1, C2.1, C6.2, C9.2, C36.1, J3.A4 (VBUS), J3.A9 (VBUS), J3.B4 (VBUS), J3.B9 (VBUS), MK1.5 (VDD), R3.1, R4.2, R6.2, R8.1, U2.5, U4.5, U5.6 (VCCB), U6.6 (VCCB)
+4V: C5.2, C8.2, C14.1, C23.1, L2.2, R18.2, U2.2, U4.2, U5.1 (VCCA), U6.1 (VCCA)
+12V: C16.1, C24.1, C33.1, C34.1, C35.1, J1.A4 (VBUS), J1.A9 (VBUS), J1.B4 (VBUS), J1.B9 (VBUS), J2.A4 (VBUS), J2.A9 (VBUS), J2.B4 (VBUS), J2.B9 (VBUS), R20.2, U8.5 (PWR), U10.1
/EYE_TO_EAR_FBK: U1.15, U3.16
EAR TO EYE AUDIO: U1.16, U3.15
GND: C1.2, C2.2, C5.1, C6.1, C8.1, C9.1, C14.2, C16.2, C23.2, C24.2, C33.2, C34.2, C35.2, C36.2, J1.0 (EH), J1.A1 (GND), J1.A12 (GND), J1.B1 (GND), J1.B12 (GND), J2.0 (EH), J2.A1 (GND), J2.A12 (GND), J2.B1 (GND), J2.B12 (GND), J3.0 (EH), J3.A1 (GND), J3.A12 (GND), J3.B1 (GND), J3.B12 (GND), MK1.3 (GND), R1.1, R2.1, R16.2, U1.3, U1.8, U1.13, U2.3, U2.8, U2.13, U2.16, U3.3, U3.8, U3.13, U4.3, U4.8, U4.13, U4.16, U5.2 (GND), U5.5 (DIR), U6.2 (GND), U6.5 (DIR), U8.2 (GND), U10.2
INT: J3.A5 (CC1), J3.B5 (CC2), R3.2, U1.9
IR SENSOR DATA: J3.A8 (SBU1), J3.B8 (SBU2), R4.1, U1.7
LED DATA_1: U2.7, U5.4 (B)
LED DATA_2: U2.6, U6.4 (B)
MIC CLOCK: MK1.4 (SCK), U4.12
MIC DATA OUTPUT: MK1.6 (SD), R2.2, U4.10
MIC WS: MK1.1 (WS), U4.9
unnamed: MK1.2 (LR), R1.2
unnamed: C27.1, U8.1 (BOOT)
unnamed: R16.1, R18.1, U8.3 (FBK)
unnamed: R20.1, U8.4 (RUN)
unnamed: C27.2, L2.1, U8.6 (SWITCH)
SCL: J3.A7 (DN1), J3.B7 (DN2), R6.1, U2.14
SDA: J3.A6 (DP1), J3.B6 (DP2), R8.2, U2.15
SHIFTED_LED_DATA_1: J1.A6 (DP1), J1.A7 (DN1), J1.B6 (DP2), J1.B7 (DN2), U5.3 (A)
SHIFTED_LED_DATA_2: J2.A6 (DP1), J2.A7 (DN1), J2.B6 (DP2), J2.B7 (DN2), U6.3 (A)

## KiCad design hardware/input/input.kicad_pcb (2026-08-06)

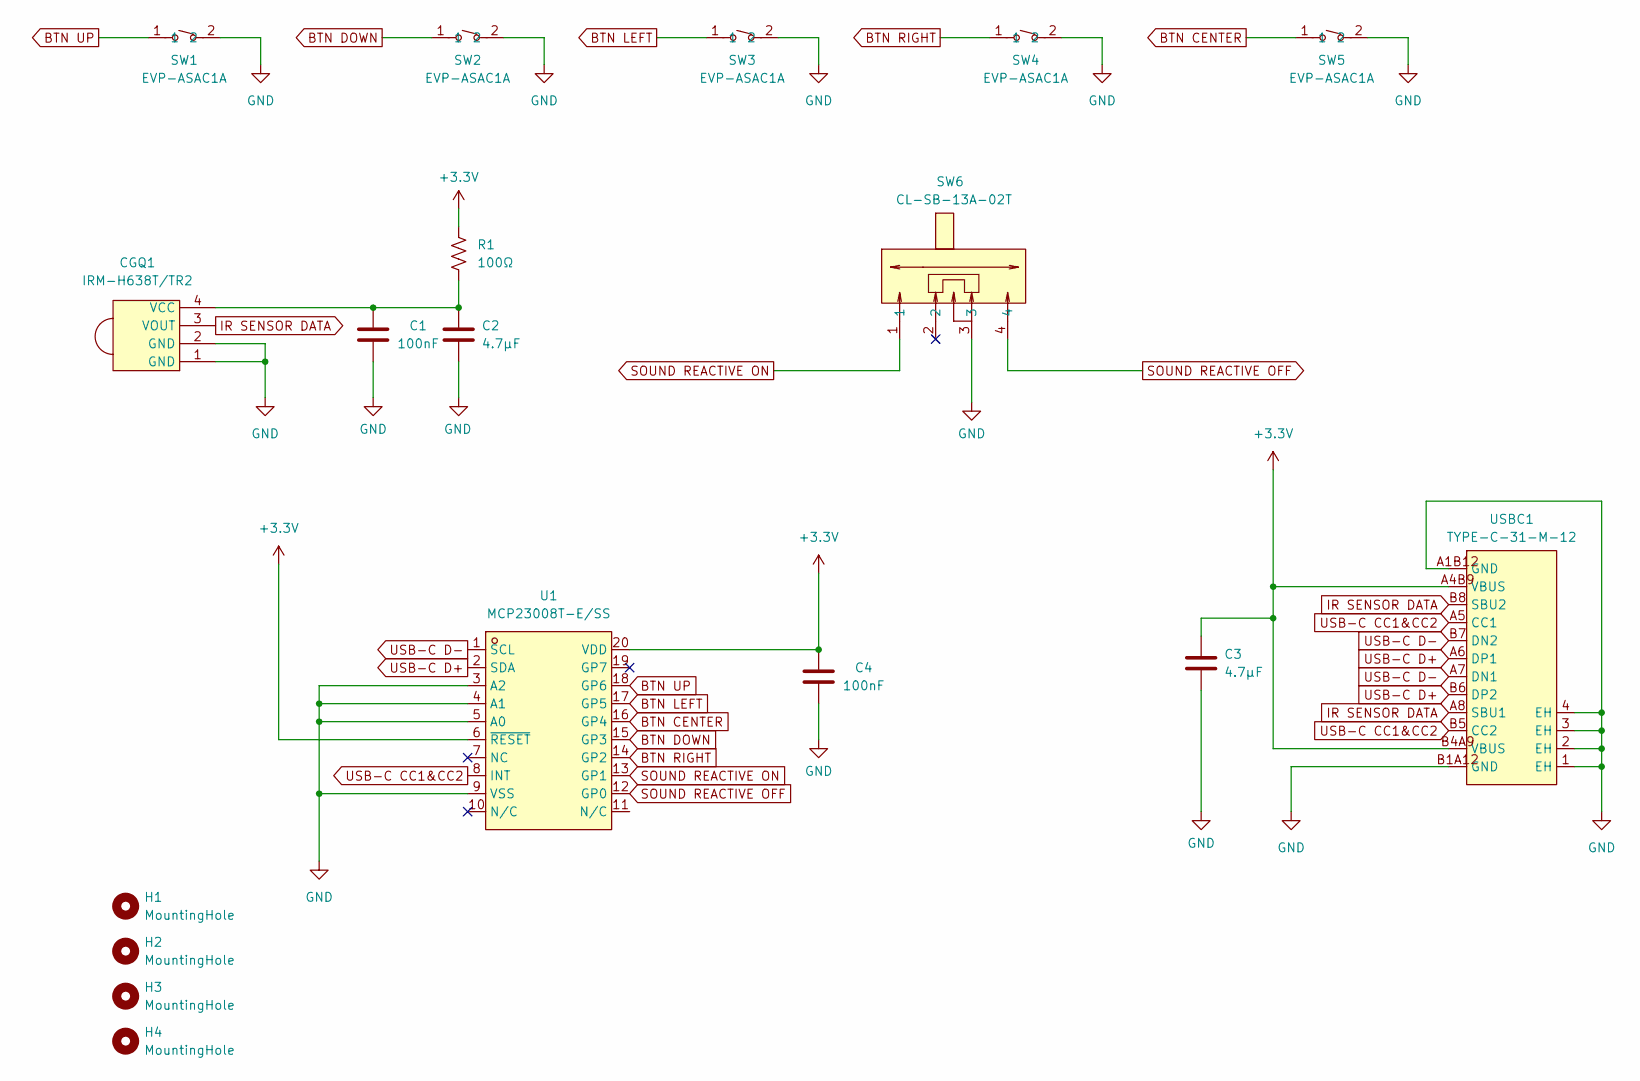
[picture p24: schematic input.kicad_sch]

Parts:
C1, C4: 100nF; C_0402_1005Metric; LCSC Part # C1525
C2, C3: 4.7µF; C_0603_1608Metric; LCSC Part # C19666
CGQ1: IRM-H638T/TR2; SENSOR-SMD_IRM-H638T-TR2-TL; MPN IRM-H638T/TR2; LCSC Part # C91447
H1, H2, H3, H4: MountingHole; MountingHole_3.2mm_M3_Pad
R1: 100Ω; R_0603_1608Metric; LCSC Part # C22775
SW1, SW2, SW3, SW4, SW5: EVP-ASAC1A; SW-SMD_PANASONIC_EVPASXXX; MPN EVP-ASAC1A; LCSC Part # C4365033
SW6: CL-SB-13A-02T; SW-SMD_CL-SB-13A-0X; MPN CL-SB-13A-02T; LCSC Part # C2921655
U1: MCP23008T-E/SS; SSOP-20_L7.2-W5.3-P0.65-LS7.8-TL; MPN MCP23008T-E/SS; LCSC Part C629435
USBC1: TYPE-C-31-M-12; USB-C_SMD-TYPE-C-31-M-12_1; MPN TYPE-C-31-M-12; LCSC Part C165948

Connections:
+3.3V: C3.2, C4.1, R1.2, U1.6 (~RESET), U1.20 (VDD), USBC1.A4B9 (VBUS), USBC1.B4A9 (VBUS)
BTN CENTER: SW5.1, U1.16 (GP4)
BTN DOWN: SW2.1, U1.15 (GP3)
BTN LEFT: SW3.1, U1.17 (GP5)
BTN RIGHT: SW4.1, U1.14 (GP2)
BTN UP: SW1.1, U1.18 (GP6)
GND: C1.2, C2.1, C3.1, C4.2, CGQ1.1 (GND), CGQ1.2 (GND), SW1.2, SW2.2, SW3.2, SW4.2, SW5.2, SW6.3, U1.3 (A2), U1.4 (A1), U1.5 (A0), U1.9 (VSS), USBC1.1 (EH), USBC1.2 (EH), USBC1.3 (EH), USBC1.4 (EH), USBC1.A1B12 (GND), USBC1.B1A12 (GND)
IR SENSOR DATA: CGQ1.3 (VOUT), USBC1.A8 (SBU1), USBC1.B8 (SBU2)
unnamed: C1.1, C2.2, CGQ1.4 (VCC), R1.1
SOUND REACTIVE OFF: SW6.4, U1.12 (GP0)
SOUND REACTIVE ON: SW6.1, U1.13 (GP1)
USB-C CC1&CC2: U1.8 (INT), USBC1.A5 (CC1), USBC1.B5 (CC2)
USB-C D+: U1.2 (SDA), USBC1.A6 (DP1), USBC1.B6 (DP2)
USB-C D-: U1.1 (SCL), USBC1.A7 (DN1), USBC1.B7 (DN2)

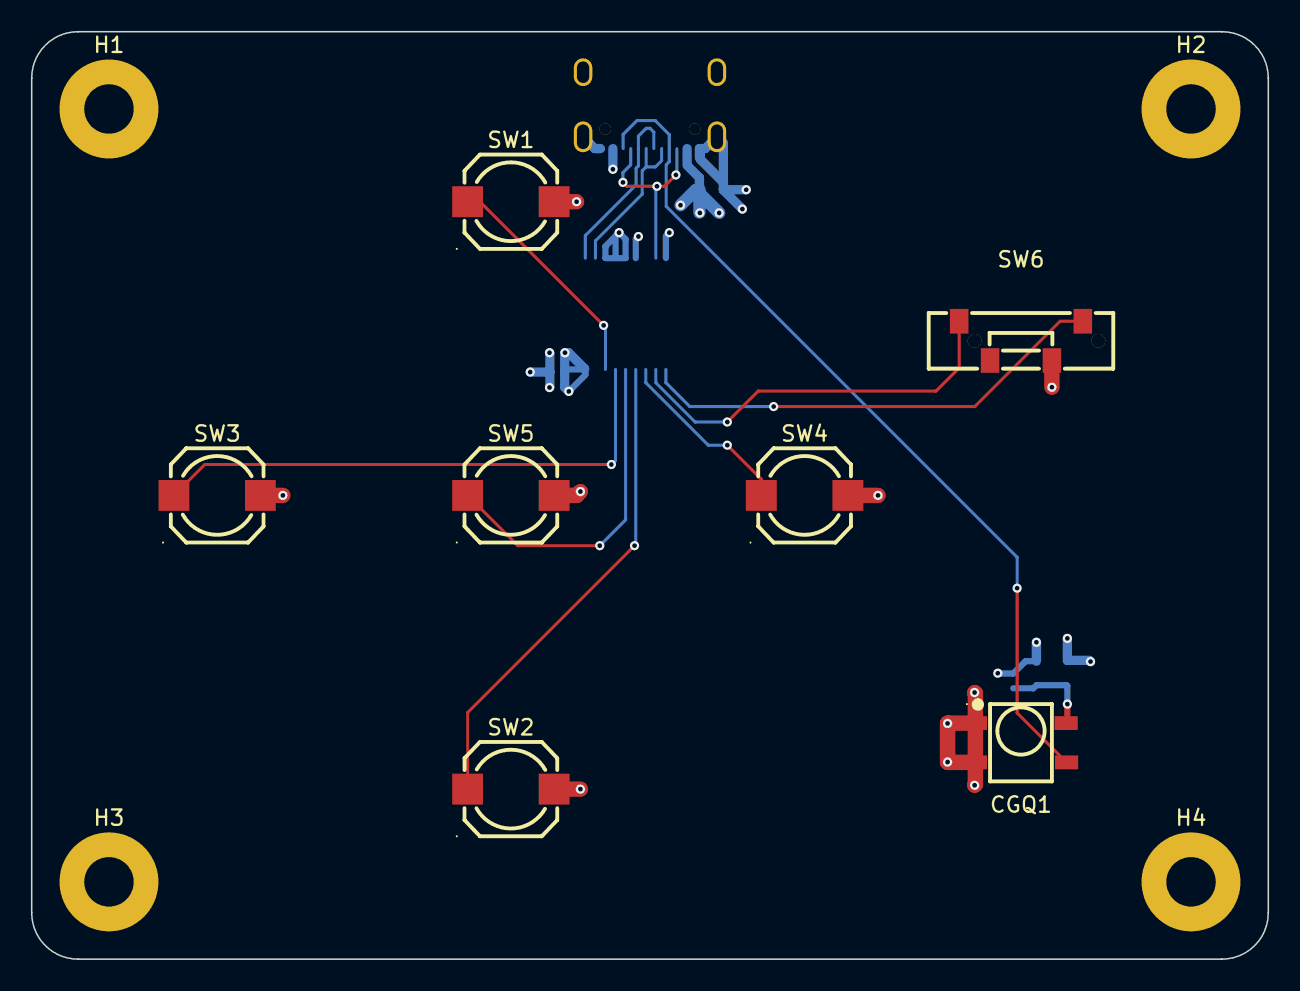
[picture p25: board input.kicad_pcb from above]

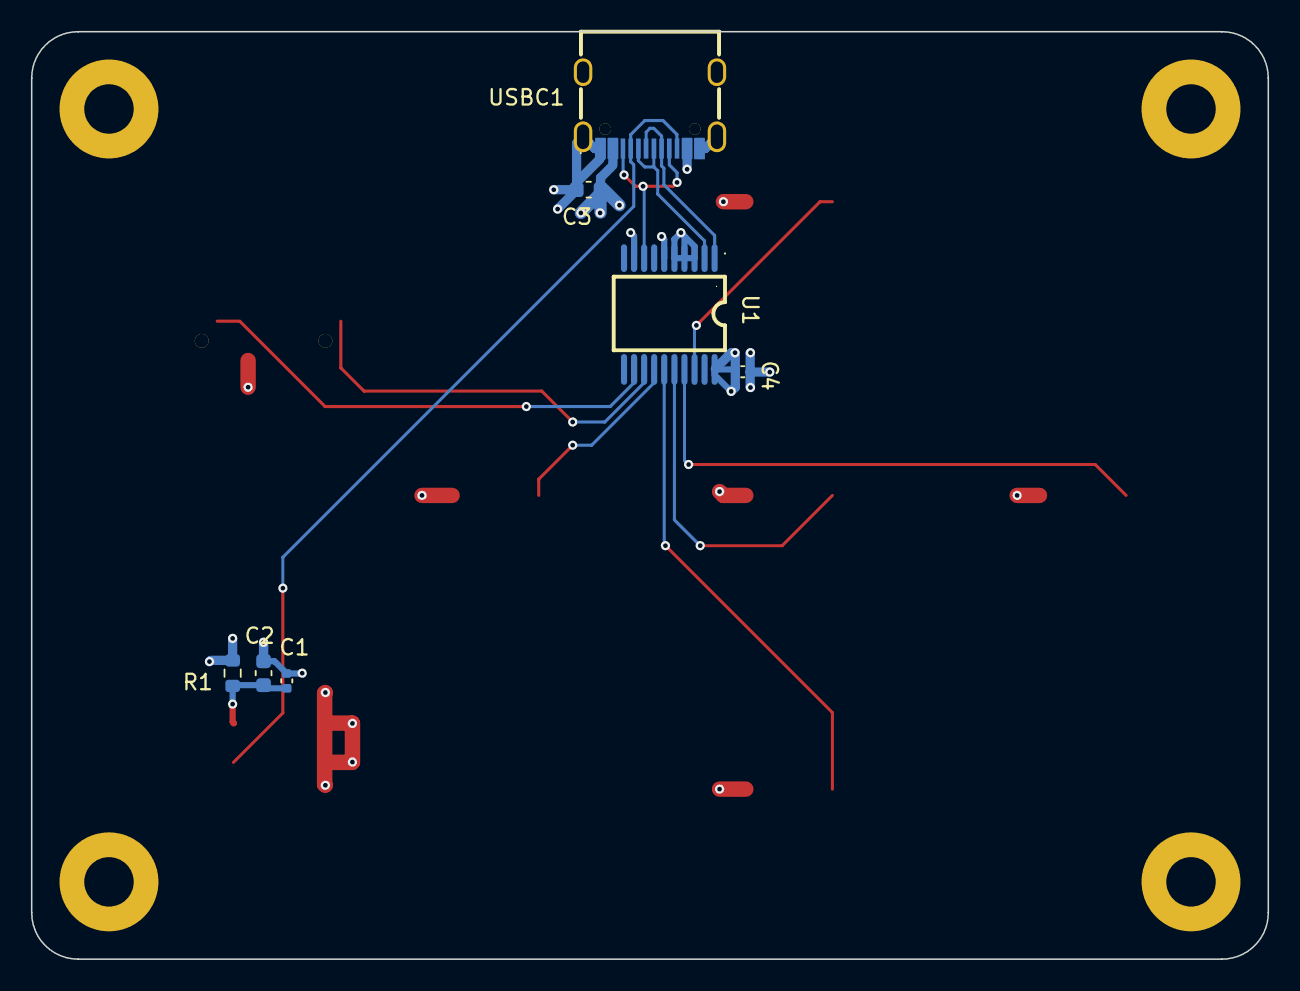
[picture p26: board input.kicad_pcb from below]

Board: 4 copper layers, 80.0 x 60.0 mm, 18 parts (7 on the bottom side), 14 nets.

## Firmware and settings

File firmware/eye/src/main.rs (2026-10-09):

mod audio;
mod diag;
mod input;
mod led;
mod patterns;
mod pins;
mod setlist;

use setlist::SetlistManager;

const TARGET_FRAME_MS: u64 = 1000 / 30; // ~33 ms -> 30 fps

fn main() -> ! {
    // A panic anywhere (main or a thread) prints over USB serial before the
    // process dies; the USB server owns the message once sent, so it still
    // reaches the host. Without this, panics are invisible.
    std::panic::set_hook(Box::new(|info| {
        diag::Diag::new().line(&format!("PANIC: {}", info));
    }));

    // Diagnostics and heartbeat come up before anything that could block, so
    // a stalled boot still reports the stage it is stuck at over USB serial.
    let boot_diag = diag::Diag::new();
    diag::stage(&boot_diag, diag::Stage::MainStart);
    diag::spawn_heartbeat();

    let tt = ticktimer::Ticktimer::new().unwrap();

    let hal = bao1x_hal_service::Hal::new();
    hal.set_preemption(true);

    // Hardware / previewer output
    let mut led_out = led::LedOutput::new();
    diag::stage(&boot_diag, diag::Stage::LedOutUp);

    // Audio receiver (continuous DMA into the UART's IFRAM ring; no interrupts, no threads)
    let mut audio = audio::AudioReceiver::new();
    diag::stage(&boot_diag, diag::Stage::AudioUp);

    // Input event channel (spawns button + IR threads)
    let (event_tx, events) = input::channel();
    input::spawn(event_tx);
    diag::stage(&boot_diag, diag::Stage::InputSpawned);

    // Seed the patterns from the hardware random number generator
    let mut seed = [0u8; 4];
    getrandom::getrandom(&mut seed).expect("no hardware random numbers");
    patterns::set_boot_seed(u32::from_le_bytes(seed));

    // Setlist manager owns pattern cycling, brightness, sound mode
    let mut setlist = SetlistManager::new(tt.elapsed_ms() as u32);

    // Frame buffer - reused every frame to avoid allocation
    let mut frame = [[0u8; 3]; led::map::LED_COUNT];

    diag::stage(&boot_diag, diag::Stage::RenderLoop);

    // Absolute next-frame deadline - prevents timing drift across frames.
    let mut next_frame = tt.elapsed_ms();

    loop {
        next_frame += TARGET_FRAME_MS;
        let frame_start = tt.elapsed_ms();

        // Ingest whatever the RX DMA ring collected; decay toward zero when ear is silent
        audio.update(frame_start as u32);

        let snapshot = audio.snapshot();

        // Drain input events and apply to setlist; it derives sound_active per event.
        input::apply_events(&events, &mut setlist, frame_start as u32, audio.is_active());

        // Determine sound-reactive mode after events: they may have changed it this frame.
        let sound_active = setlist.sound_active(audio.is_active());

        // Advance cycling timer
        setlist.tick(frame_start as u32, sound_active);

        // Render current pattern (compositing any in-flight transition) into frame buffer
        setlist.render(frame_start as u32, &snapshot, sound_active, &mut frame);

        // Apply global brightness
        let brightness = setlist.brightness();
        if brightness < 1.0 {
            for led in frame.iter_mut() {
                led[0] = (led[0] as f32 * brightness) as u8;
                led[1] = (led[1] as f32 * brightness) as u8;
                led[2] = (led[2] as f32 * brightness) as u8;
            }
        }

        // Send to LEDs (WS2812 or previewer serial depending on feature flag)
        led_out.send_frame(&frame);

        // Sleep until the next scheduled frame deadline.
        let now = tt.elapsed_ms();
        if now < next_frame {
            tt.sleep_ms((next_frame - now) as usize).ok();
        } else {
            // Overran the deadline; resync so we don't sprint through a burst of catch-up frames.
            next_frame = now;
        }
    }
}

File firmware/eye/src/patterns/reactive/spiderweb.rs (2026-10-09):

use core::f32::consts::PI;

use crate::audio::Audio;
use crate::led::geom::{BOARD_COUNT, LEDS_PER_BOARD};
use crate::led::map::{Led, LED_COUNT, LED_MAP};
use crate::patterns::{Frame, Pattern, Rng, Shot, hsv};
use triangel_shared::tuning::spiderweb::*;

/// The tile outlines form straight lines across the fixture, nine in each of three
/// directions: horizontal and the two 60-degree slants.
const LINES_PER_FAMILY: usize = 9;
const MAX_LINES: usize = LINES_PER_FAMILY * 3;
/// How close an LED's direction must be to one of the three. Corner LEDs fail it.
const DIR_TOLERANCE: f32 = 12.0 * PI / 180.0;
/// LEDs in one row share an offset to within this; neighboring rows are 12 mm apart.
const ROW_MERGE_MM: f32 = 1.0;

/// (hue, sat): half white, plus pale blue, lavender and violet.
const PALETTE: [(f32, f32); 6] =
    [(0.0, 0.0), (0.0, 0.0), (0.0, 0.0), (205.0, 0.30), (260.0, 0.32), (278.0, 0.50)];

struct Line {
    family: usize,
    offset: f32,
    /// The latest two shots; the brighter one shows.
    shots:  [Shot; 2],
}

/// A faint web that pulses on each beat. A beat lights whole lines, white at first, then
/// fading through their color; a drop lights every line.
pub struct Spiderweb {
    rng:      Rng,
    lines:    Vec<Line>,
    /// Which line each LED is on.
    led_line: [u8; LED_COUNT],
    /// When the last beat landed and how hard.
    pulse_ms: u32,
    pulse:    f32,
}

impl Spiderweb {
    pub fn new() -> Self {
        let leds = &LED_MAP;
        let normal: [(f32, f32); 3] = core::array::from_fn(|f| {
            let a = f as f32 * PI / 3.0;
            (-a.sin(), a.cos())
        });
        let across = |f: usize, led: &Led| normal[f].0 * led.wx + normal[f].1 * led.wy;

        // Which LED is at each position on each tile. Positions start at 1, and there is a
        // spare empty slot past the last.
        let mut at = [[u16::MAX; LEDS_PER_BOARD + 2]; BOARD_COUNT + 1];
        for (i, led) in leds.iter().enumerate() {
            at[led.board_id as usize][led.local_idx as usize] = i as u16;
        }

        // Each LED's direction from the LEDs either side of it on its tile.
        let mut family = [u8::MAX; LED_COUNT];
        for (i, led) in leds.iter().enumerate() {
            let (b, l) = (led.board_id as usize, led.local_idx as usize);
            if l == 0 || l + 1 >= LEDS_PER_BOARD + 2 {
                continue;
            }
            let (p, n) = (at[b][l - 1], at[b][l + 1]);
            if p == u16::MAX || n == u16::MAX {
                continue;
            }
            let (p, n) = (&leds[p as usize], &leds[n as usize]);
            let mut a = (n.wy - p.wy).atan2(n.wx - p.wx);
            if a < 0.0 {
                a += PI;
            }
            for f in 0..3 {
                let d = (a - f as f32 * PI / 3.0).abs();
                if d.min(PI - d) < DIR_TOLERANCE {
                    family[i] = f as u8;
                }
            }
        }

        // Group each direction's LEDs into rows by offset. The nine largest rows are the
        // lines; smaller ones are stray corner LEDs.
        let mut lines = Vec::new();
        for f in 0..3 {
            let mut offs: Vec<f32> = leds
                .iter()
                .zip(family.iter())
                .filter(|&(_, &fam)| fam as usize == f)
                .map(|(led, _)| across(f, led))
                .collect();
            offs.sort_unstable_by(|a, b| a.total_cmp(b));
            let mut rows: Vec<(usize, f32)> = Vec::new();
            let mut run = (0usize, 0.0f32, f32::MIN);
            for o in offs {
                if o - run.2 > ROW_MERGE_MM && run.0 > 0 {
                    rows.push((run.0, run.1 / run.0 as f32));
                    run = (0, 0.0, o);
                }
                run = (run.0 + 1, run.1 + o, o);
            }
            if run.0 > 0 {
                rows.push((run.0, run.1 / run.0 as f32));
            }
            rows.sort_unstable_by(|a, b| b.0.cmp(&a.0));
            for &(_, offset) in rows.iter().take(LINES_PER_FAMILY) {
                lines.push(Line { family: f, offset, shots: [Shot::NONE; 2] });
            }
        }

        // Every LED, corners included, joins the line nearest to it.
        let mut led_line = [0u8; LED_COUNT];
        for (i, led) in leds.iter().enumerate() {
            let mut best = (0usize, f32::MAX);
            for (li, line) in lines.iter().enumerate() {
                let d = (across(line.family, led) - line.offset).abs();
                if d < best.1 {
                    best = (li, d);
                }
            }
            led_line[i] = best.0 as u8;
        }

        Spiderweb { rng: Rng::new(0x5157_3EB0), lines, led_line, pulse_ms: 0, pulse: 0.0 }
    }

    /// Lights line `li`, replacing whichever of its two shots ends sooner, so a long drop
    /// shot outlasts the beats after it.
    fn fire(&mut self, li: usize, t_ms: u32, strength: f32, hold: f32, fade: f32) {
        let (hue, sat) = self.rng.pick(&PALETTE);
        let line = &mut self.lines[li];
        let remaining = |s: &Shot| {
            if s.strength <= 0.0 { i32::MIN } else { s.end_ms().wrapping_sub(t_ms) as i32 }
        };
        let slot = if remaining(&line.shots[0]) <= remaining(&line.shots[1]) { 0 } else { 1 };
        line.shots[slot] = Shot { start_ms: t_ms, strength, hue, sat, hold_ms: hold, fade_ms: fade };
    }
}
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

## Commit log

2026-05-16 changed orientation of a couple leds
    [triangle.kicad_pcb]
2026-05-24 add clippy fixes and add clippy to pre-commit
    [audio.rs]
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2026-05-26 routing efforts for the triangle
    [triangle.kicad_pcb, triangle.kicad_sch]
2026-05-27 fix routing and add test points
    [triangle.kicad_pcb, triangle.kicad_sch]
2026-05-27 kicad settings updates
    [triangle.kicad_pcb]
2026-05-28 exclude fill zones around mounting holes
    [triangle.kicad_pcb]
2026-05-28 slight shape adjustment
    [triangle.kicad_pcb]
2026-05-28 small hardware tweaks
    [triangle.kicad_pcb]
2026-05-28 make exclusion zones around mounting holes circles
    [triangle.kicad_pcb]
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2026-05-30 add cap to triangle board and start controller board
    [components.kicad_sch, controller.kicad_pcb, controller.kicad_sch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]
2026-05-30 use different socket for data vs power to avoid accidents
    [components.kicad_sch, triangle.kicad_pcb, triangle.kicad_sch]
2026-05-30 remove unnecessary test pad and add silkscreen for sockets
    [components.kicad_sch, triangle.kicad_pcb, triangle.kicad_sch]
2026-05-31 remove wrong part from controller board
    [controller.kicad_sch]
2026-05-31 holes only.
    [triangle.kicad_pcb, triangle.kicad_sch]
2026-06-02 updating components on triangle board - in progress
    [triangle.kicad_pcb, triangle.kicad_sch]
2026-06-04 trying and failing to fix the usb-c
    [triangle.kicad_pcb, triangle.kicad_sch]
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2026-06-06 add more power items
    [triangle.kicad_pcb, triangle.kicad_sch]
2026-06-07 fixing schematic
    [triangle.kicad_sch, usb_and_power.kicad_sch]
2026-06-07 trying to fix schematic
    [triangle.kicad_pcb, usb_and_power.kicad_sch]
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2026-06-07 more moving things around
    [triangle.kicad_pcb, triangle.kicad_sch]
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2026-06-07 fix labels
    [triangle.kicad_pcb]
2026-06-08 remove old usb from controller
    [components.kicad_sch]
2026-06-08 placing more components for controller board
    [components.kicad_sch, usb-c_to_triangles.kicad_sch, voltage_converters.kicad_sch]
2026-06-10 more controller board work, consolidation/revision of design
    [baochip_2_-_ear.kicad_sch, components.kicad_sch]
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2026-06-11 more controller board work
    [baochip_2_-_ear.kicad_sch, components.kicad_sch, controller.kicad_sch]
2026-06-14 adding labels and the barrel connector
    [controller.kicad_sch, usb-c_to_triangles.kicad_sch, voltage_converters.kicad_sch]
2026-06-14 hook up all the dabao headers and one more voltage converter
    [controller.kicad_sch, usb-c_to_triangles.kicad_sch, voltage_converters.kicad_sch]
2026-06-15 re-order the numbers on the schematic for tidiness
    [components.kicad_sch, controller.kicad_sch, usb-c_to_triangles.kicad_sch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]
2026-06-15 renaming parts for consistency
    [components.kicad_sch, controller.kicad_sch, usb-c_to_triangles.kicad_sch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]
2026-06-15 fix part numbering
    [triangle.kicad_sch, usb_and_power.kicad_sch]
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2026-06-15 making initial pcb file and importing items
    [controller.kicad_pcb]
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2026-06-15 updating symbols and board
    [controller.kicad_pcb, usb-c_to_triangles.kicad_sch]
2026-06-15 moving some more things around
    [controller.kicad_pcb]
2026-06-17 rotate/move around items on controller board
    [controller.kicad_pcb]
2026-06-18 adding some more stuff
    [components.kicad_sch, controller.kicad_pcb]
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2026-06-19 placement and initial routing
    [controller.kicad_pcb]
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2026-06-20 rearrange the pins a bit and less insane routing
    [controller.kicad_pcb, controller.kicad_sch]
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2026-06-22 fix: reset pattern cycle timer on manual next/prev
    [main.rs, setlist.rs]
2026-06-22 fix: clear audio activity flag when ear stops sending
    [audio.rs]
2026-06-22 fix: retry audio UART init instead of dying on first failure
    [audio.rs]
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2026-07-01 ear: fix stale audio-level protocol docs and comment
    [main.rs, uart_out.rs]
2026-07-01 eye: guard zero-duration transition, refresh sound mode after input, fix map comment
    [main.rs, setlist.rs]
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2026-07-04 eye: revert flame to heat model, hash-decorrelate flicker phases
2026-07-06 eye: add Squall ambient pattern - boiling sea, drifting clouds, sparse lightning
    [setlist.rs]
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2026-07-08 feedback on the controller
    [components.kicad_sch, controller.kicad_sch, usb-c_to_triangles.kicad_sch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]
2026-07-12 updates to schematic based on feedback
    [controller.kicad_pcb, triangle.kicad_pcb, usb_and_power.kicad_sch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]
2026-07-13 fix up a few more things based on feedback
    [components.kicad_sch, controller.kicad_pcb, voltage_converters.kicad_sch]
2026-07-17 tiny board update for controller
    [components.kicad_sch]
2026-07-17 i2s code that may or may not work
    [audio.rs, main.rs]
2026-07-17 remove unused capacitor from triangle board
    [triangle.kicad_pcb]
2026-07-18 change a part on controller board, make production files
    [bom.csv, components.kicad_sch, controller.kicad_pcb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]
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2026-07-21 script for making brackets, also scoot over components on triangle board
    [triangle.kicad_pcb]
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2026-07-25 trying to fix uart
    [uart_out.rs]
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2026-07-28 fusion file for brackets
    [triangle brackets.f3d]
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2026-07-31 empty input board to start us off
    [input.kicad_pcb, input.kicad_sch]
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2026-08-01 rearranging shared files and input board beginnings
    [controller.csv, controller.kicad_pcb, input.kicad_pcb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]
2026-08-01 triangle rework to use new symbols and get all shapes
    [triangle.kicad_pcb, usb_and_power.kicad_sch]
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2026-08-01 more input board work
    [input.kicad_pcb]
2026-08-01 a few more changes for the input board
    [input.kicad_pcb, input.kicad_sch]
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2026-08-01 working on updating controller board
    [controller.kicad_pcb, controller.kicad_sch, voltage_converters.kicad_sch]
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2026-08-02 reorganize the triangel brackets location
    [triangle bracket - 3 way.step, triangle bracket - 6 way.step, triangle brackets.f3d]
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2026-08-04 tiny change to triangle routing
    [triangle.kicad_pcb]
2026-08-04 updates for triangle production
    [positions.csv]
2026-08-06 cleanup and prep for ordering
    [bom.csv, controller.kicad_pcb, controller.kicad_sch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]
2026-08-06 everything on one side for the controller
    [controller.kicad_pcb, positions.csv]
2026-08-07 back input board enclosure update
    [input-board-back-tray.step, input-board-front-plate.step, input-board.step]
2026-08-10 old 2020 discontinued.. switch to new one
    [triangle.kicad_pcb, triangle.kicad_sch]
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2026-08-15 fix corner bracket corner
    [triangle brackets - corner bracket corner.step]
2026-08-19 uzumaki pattern and controller bracket
    [controller_bracket.step]
2026-08-19 forgot to add controller step file
    [controller.step]
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2026-08-25 redo corner bracket corner.
    [triangle brackets - corner bracket corner.step]
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2026-08-30 add ESD to triangles
    [triangle.kicad_pcb, usb_and_power.kicad_sch]
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2026-09-09 make ear more resistant to loud sudden short noises and make spectrum more beautiful
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2026-09-16 new pattern, performance improvements, etc
    [pin.kicad_pcb]
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2026-10-06 tidy the pattern rng, precompute per-led values in rainbow and fubuki, and correct the docs
    [audio.rs, firework.rs, rainbow.rs]
2026-10-06 replace the per-led sin calls in rainbow and fubuki, and share the sine-of-a-sum helper
    [effervesce.rs, rainbow.rs]
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2026-10-09 release the uart csr page when the audio link's second mapping fails
    [audio.rs]
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2026-10-11 drop previewer frames that were cut short instead of drawing them
2026-10-11 fix the bridge's marker handling, report serial and frame stalls, and correct the map header
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2026-10-11 correct the previewer readme: chain order, frame format, status, and removed tools
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2026-10-11 resync inside a failed frame, share the level scale, and size the frame from one count
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2026-10-11 stop the led bio program at the last led, and correct its send time and comments
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2026-10-11 give effervesce's shapes an enum, share the respawning slot helper with fubuki, and correct the swell comment
2026-10-11 name squall's and flame's per-frame structs, set up squall's timers in one place, and correct two comments
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2026-10-11 check geom.rs is current before a commit, correct how map.rs says it is made, and move the remote picture to the eye
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2026-10-26 update frame corner slightly to fix jlcpcb problem
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2026-10-28 shorter beat refractory name and wire parameter names in shared
2026-10-28 module doc, short pin names and a safety note in the ear's audio code
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2026-11-03 fix some stuff in the 3D models for components as well as make the jack hang off the edge of the board a bit
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2026-11-06 remove power flags, tidy eye and ear layout, swap esd diodes to h5vud5u
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2026-11-07 power regulator fixes
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2026-11-11 fix up the new controller enclosure
